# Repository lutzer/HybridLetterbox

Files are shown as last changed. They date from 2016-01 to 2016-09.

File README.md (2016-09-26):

# Hybrid Letterbox

## Installation

* For instructions how to setup the raspberry pi from scratch see file: [docs/pi-installation.md](docs/pi-installation.md)

### Setup Letterbox for the first time

* go to HybridLetterbox dir and update to the newest version: `git pull`
* modify two config files
  * go to src/server/node directory and copy config file: `cp config.defaultjs config.js` and modify file to your needs
  * go to src/letterbox/ and copy ini file: `cp letterbox.default.ini letterbox.ini `  and modify it to your needs

## Development

### Python Test Scripts

* go to src folder and call testscripts by sudo `python2 -m letterbox.tests`

### Node Testscripts

* install pm2 `npm install pm2 -g`

* go to `cd src/www`
  * start testscripts by calling `npm test`

### Configure Atmega Head Board

see  [atmega-installation.md](atmega-installation.md)`

## Update

### 10.9.2016

* edit  `sudo nano /etc/systemd/system/letterbox.service` and change value:

  ```
  RemainAfterExit=false
  ```

* `git pull`

* start admin node script on port 9000

  * `cd src/server/admin/ `

  * `npm install`

  * `cp config.default.js  config.js` and adjust parameters in editor `nano config.js` , these 3 parameters have to be changed:

      ```
      /* AUTH DATA */
      authName: 'admin',
      authPassword: 'password',
      sudoPassword: 'password'
      ```

  * create startup script for admin server: `pm2 start main.js --name LetterboxBackend` and save `pm2 save`

* reboot with `sudo reboot`

* access admin backend by going to `192.168.72.2:9000` within your browser

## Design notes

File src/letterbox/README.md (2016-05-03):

# Hybrid Letterbox Python Scripts

Contains the scripts to control the hardware and camera on the letterbox. Sends pictures either to local node server, or to a central web server.

## Setup Letterbox
* TODO

## Start Script

* sudo python2 letterbox_service.py

## Test Scripts

* Call testscripts by `sudo python2 -m src.python.tests`

## Deploy

* `sudo systemctl enable letterbox.service`

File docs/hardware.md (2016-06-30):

# Letterbox Hardware

## Headboard

### Pin Layout

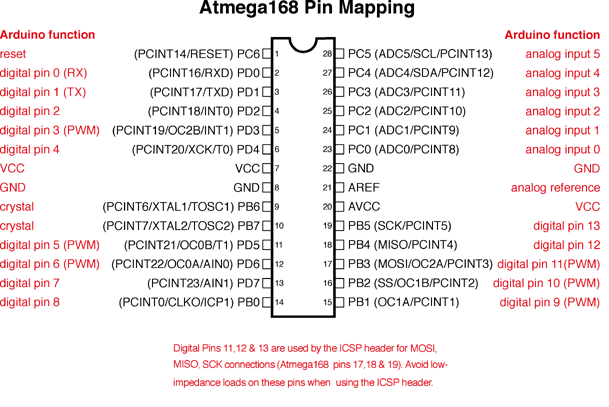
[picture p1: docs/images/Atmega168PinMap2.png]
Atmega168PinMap2
 

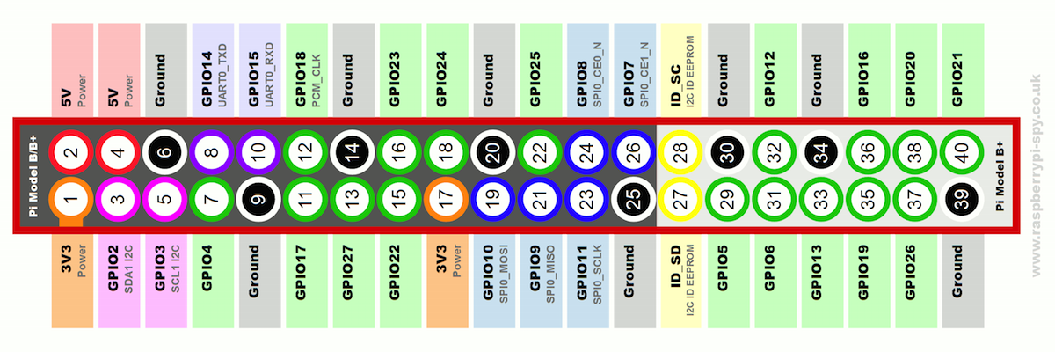
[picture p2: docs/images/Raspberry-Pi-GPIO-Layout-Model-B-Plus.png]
Raspberry-Pi-GPIO-Layout-Model-B-Plus
 

## Camera Board

* Transistor Base: 330 Ohm Resistor to GPIO
* Transitor: 547 NPN (Footprint: TO-92)
* LED 20mA Through hole White:  Resistor 100 Ohm each
* SMD LEDs white 3x20mA: http://www.produktinfo.conrad.com/datenblaetter/175000-199999/183097-da-01-en-LED_TOP_VIEW_NEUTRALWS_STW9T36B_D.pdf
  * missing triangular edge marks the vcc pins, opposite site is gnd **(check before soldering, normally it should be the other way around)**
  * resistor for SMD TRIPLE LED (60mA) 3.2 V: 33 Ohm

## Headboard

### Photoresistor

* Pin 23 (A0) with 10 kOhm pulldown resistor

### Serial Connector

* 10uF 50V Capacitor (Footprint: D5 L11)
* 10 kOhm Resistor to 5V
* TX: PIN1, RX: PIN0

### Reed Switch

* PIN4 with 10 kOhm Current limiting resistor

## Stepper

* Driver: SN754410 Half Bridge
* Connected Pins: 

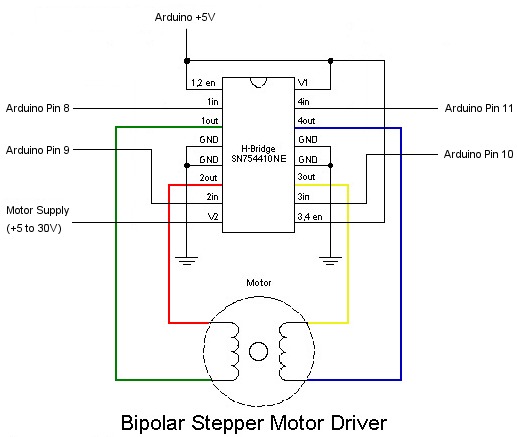
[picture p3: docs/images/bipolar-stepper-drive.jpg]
bipolar-stepper-drive


## Problems

- Headboard
  * [x] Make Serial port a 5 pin port (rx, tx, vcc, gnd, dts) to be able to program atmega with turned of rasp pi. or: jumper to block serial connection to rasp pi
  * [x] Connect all gnds,5v and 3v together to be able to power it from another power src than rasp pi
  * [x] mixed up RX and TX Connection to rasp pi
  * [ ] ~~Feedback LED on wrong pin for wpm: do we need that?~~
  * [ ] mark + on led pin headers, mark stepper header
  * [ ] transistor holes too far apart
  * [x] **STILL TO TEST:** mixed up RX / TX on serial connector to atmega. cross RX <-> TX, take care to not change this on rasp pi
  * [ ] spannungsabfall an den beiden dioden zu hoch, entfernen?
- Camera Board
  * [ ] Move power connector to bottom side
- Stepper Board
  * [ ] Hard to solder via on upper fill. Need to put wire between the two ground holes or find another solution

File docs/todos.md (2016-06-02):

# TODOs

* [ ] Feedback Mechanismus
      * 3 stufiges feedback: Aufforderung, Bearbeitung, Bestätigung

* [ ] Stepper Achse fixen
* [ ] Stepper PCB
* [ ] Neues Headboard PCB

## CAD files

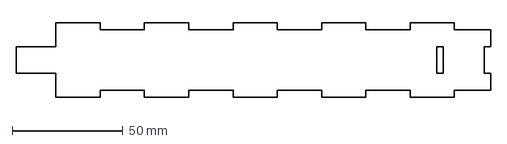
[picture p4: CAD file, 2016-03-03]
resources/lasercut/outer_frame/side_x2.dxf
214.5 x 33.5 mm

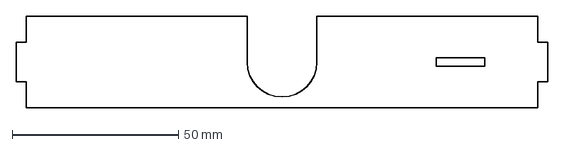
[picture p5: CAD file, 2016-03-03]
resources/lasercut/outer_frame/back1.dxf
160.0 x 27.5 mm

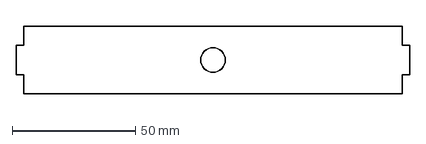
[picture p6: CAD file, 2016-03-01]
resources/lasercut/outer_frame/back2.dxf
160.0 x 27.5 mm

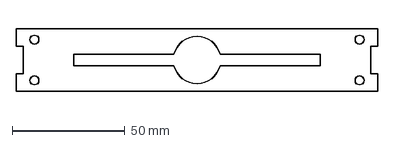
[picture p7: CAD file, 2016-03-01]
resources/lasercut/outer_frame/front1_x5.dxf
160.0 x 27.5 mm

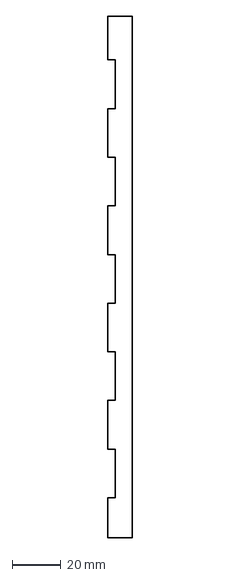
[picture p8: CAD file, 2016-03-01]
resources/lasercut/outer_frame/strebe_x4.dxf
10.0 x 214.5 mm

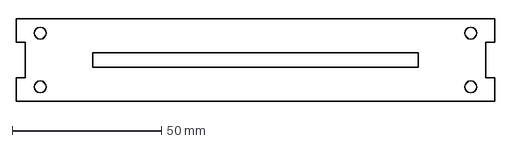
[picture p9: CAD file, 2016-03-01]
resources/lasercut/outer_frame/front2.dxf
160.0 x 27.5 mm

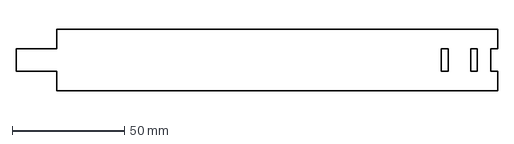
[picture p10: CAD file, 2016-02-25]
resources/lasercut/outer_frame/sides.dxf
214.0 x 27.5 mm

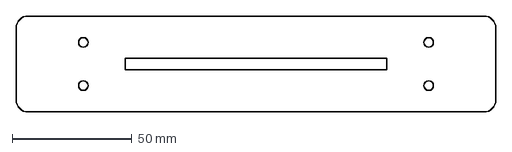
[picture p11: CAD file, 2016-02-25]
resources/lasercut/outer_frame/front3.dxf
200.0 x 40.0 mm

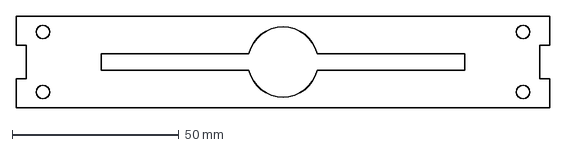
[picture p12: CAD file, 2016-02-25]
resources/lasercut/outer_frame/front1.dxf
160.0 x 27.5 mm

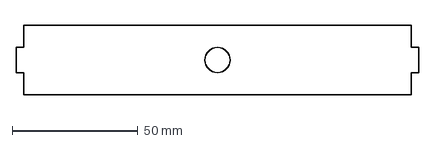
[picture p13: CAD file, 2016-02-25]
resources/lasercut/outer_frame/back3.dxf
160.0 x 27.5 mm

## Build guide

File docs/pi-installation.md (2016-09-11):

# Hybrid Letterbox

## Installation Guide for Raspberry Pi

### Prepare SD Card

1. Download Arch linux image and 

   * use apple pi-baker to transfer image to sd card

   * or:

     ``` shell
     # identify sd card
     diskutil list

     # unmount sd card
     diskutil unmountDisk /dev/diskX

     # copy data to sd card (will take a while)
     sudo dd bs=1m if=image.img of=/dev/rdiskX
     ```

2. Plug the raspberry pi ethernet cable into router or

   Setup dhcp server on mac, plug it into the macs ethernet port

   and use LanScan to detect its ip adress

### Resize partition

```
sudo fdisk /dev/mmcblk0
-----
* press p to print partion table:
Device         Boot  Start     End Sectors  Size Id Type
/dev/mmcblk0p1        2048  206847  204800  100M  c W95 FAT32 (LBA)
/dev/mmcblk0p2      206848 3913726 3706879  1.8G 83 Linux
* take note of start sector of Linux partition: 206848
* press d -> 2 to delete second partition
* prress n -> p -> 2 to create primary partition on number 2 with startsector as noted before. choose end sector whatever size you need your partition to be.
* press w to write partion table
-----
sudo reboot
 
```

### Setup ip adress of pi or skip or use dhcp server

* setup rasp pi ip adress
  1. `sudo ip addr add 192.168.72.2/24 broadcast 192.168.72.255 dev eth0`
  2. `sudo ip route add default via 192.168.72.1`
  3. persistent config see: https://wiki.archlinux.org/index.php/
  4. Network_configuration#Configure_the_IP_address

* or see below (assign ip address by dhcp)

### Login into PI and create user accounts

1. type ssh root@ip password is root
2. change root password (to <rootpasswd>): `passwd`
3. create new user account: `useradd -m letterbox` -> `passwd letterbox`
4. change hostname: `nano /etc/hostname`

### Change keyboard and timezone Settings

1. set berlin timezone: `nano ~/.bashrc: TZ='Europe/Berlin'; export TZ` 
2. set german keyboard: `localectl set-keymap --no-convert de`

### Update Pacman Packaging System and configure sudo

1. update pacman: `pacman -Syy`

2. install sudo: `pacman -S sudo`

   setup sudo for user: `EDITOR=nano visudo` -> add line `letterbox ALL=(ALL) ALL`

### Install Packages

1. install time deamon ntpd: `pacman -S ntp`

2. enable ntpd: `systemctl enable ntpd`
3. install additional packages: `git,`

### Install and Setup Nodejs Webserver

1. install node: `pacman -S nodejs npm`

2. install pm2 node process manager: `pacman -S pm2`

3. install nginx: `sudo pacman -S nginx`

   ``` shell
   # create file /etc/nginx/sites-enabled/hybridletterbox

   # DOMAIN: www.hybridletterbox.de
   server {
     listen       80;
     server_name  localhost;
     root    /home/letterbox/www;

     #charset koi8-r;

     #access_log  logs/host.access.log  main;

     #location / {
     #	index  index.html index.htm index.php;
     #}
     
     # forward to letterbox node server
     location / {
       proxy_pass http://127.0.0.1:8081;
       proxy_http_version 1.1;
       proxy_set_header Upgrade $http_upgrade;
       proxy_set_header Connection 'upgrade';
       proxy_set_header Host $host;
       proxy_cache_bypass $http_upgrade;
     }
   }
   ```
4. enable nginx: `sudo systemctl enable nginx` and start `sudo systemctl start nginx`

### Install MongoDb

1. `sudo pacman -S mongodb`

2. enable startup script: `sudo systemctl enable mongodb.service`

3. change systemd script `nano /lib/systemd/system/mongodb.service` ro run mongodb in journal mode

   ```
   [Unit]
   Description=High-performance, schema-free document-oriented database
   After=network.target

   [Service]
   User=mongodb
   ExecStart=/usr/bin/mongod --quiet --journal --config /etc/mongodb.conf

   [Install]
   WantedBy=multi-user.target
   ```

(might neeed to `sudo rm /var/lib/mongodb/mongod.lock`)

### Enable Serial Connection

see  http://rpi900.com/tutorials/using-the-serial-port.html

- prevent rasp pi from broadcasting boot messages over serial

- `sudo nano /boot/cmdline.txt`
  - change content to `root=/dev/mmcblk0p2 rw rootwait console=tty1 selinux=0 plymouth.enable=0 smsc95xx.turbo_mode=N dwc_otg.lpm_enable=0 elevator=noop` (delete both entries with xxxx=ttyAMA0,115)
- disable terminal service for serial port: `sudo systemctl disable serial-getty@ttyAMA0.service`
- give user letterbox access to serial console: `$sudo usermod -a -G uucp letterbox` and reopen terminal
- configure serial port to use 9600 baud `stty -F /dev/ttyAMA0 9600`
- install picocom for testing: `sudo pacman -S picocom`
  - start serial monitor: `picocom -b 9600 /dev/ttyAMA0` or by `cat /dev/ttyAMA0 `
  - send commands by just typing in picocom **(Newline charatcter is send as \r)** or by sending `echo "Command" > /dev/ttyAMA0` (newline character is send as \n)

### Setup Camera

1. nano /boot/config.txt, add following lines to the end:

   ```shell
   ## Enable Camera
   start_file=start_x.elf
   fixup_file=fixup_x.dat
   ```

2. nano ~/.bashrc:

   ```shell
   # add camera commands to path
   export PATH=$PATH:/opt/vc/bin
   ```

3. `nano /etc/modprobe.d/blacklist.conf`, add:

   ```
   blacklist i2c_bcm2708
   ```

4. reboot system

5. to test camera: `raspistill -o image.jpg` or `raspistill -t 99999`

   - more info here: https://www.raspberrypi.org/documentation/usage/camera/raspicam/raspistill.md

6. install python lib: pip install picamera

   -  also install: sudo pacman -S python-pillow (PIL image lib)

### Install Python 2

* `pacman -S python2 gcc python2-pip`
* `pip2 install pyserial picamera enum requests RPi.GPIO`
  `Collecting pyserial scriptine`
* pacman -S python2-scipy

### Install opencv

1. pacman -S pkg-config

2. pacman -S opencv (also includes python cv2 wrapper)

   1. might need to upgrade nettle and gnutls by `pacman -S gnutls nettle`

   2. also `sudo pip2 install numpy` or `sudo pacman -S python2-numpy`

### Autostart Python Scripts

1. create a file in folder /etc/systemd/system : letterbox.service

2. insert:

   ``` shell
   [Unit]

   Description=Launches letterbox script

   After=network.target

   [Service]

   Type=simple

   WorkingDirectory=/home/letterbox/HybridLetterbox/src/letterbox/

   ExecStart=/bin/python2 letterbox_service.py

   RemainAfterExit=false

   [Install]

   WantedBy=multi-user.target
   ```

1. `sudo systemctl daemon-reload`

2. `sudo systemctl enable letterbox.service`

   ( if not working: make sure all paths in python script are absolute)

   ( to stop: `systemctl stop letterbox.service` or `systemctl disable letterbox.service`

### Autostart pm2 manager

1. install pm2: `sudo pip2 install pm2`
2. enable startup: `pm2 startup systemd `
3. automatically start server: `pm2 start src/server/node/main.js --name hybrid-letterbox` and save with `pm2 save`

## Camera Calibration

* put a book behind the calibration pattern to raise it a bit up
* run `./letterbox.py camera —calibrate` within src/letterbox folder

## Configure Tp-Link Router

* first **upgarde firmware**! Then install configuration image or configure it manually.
* setup dhcp reservation of rasp pi to always assign it to 192.168.72.2
* change admin pw!

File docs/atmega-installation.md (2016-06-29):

# Setup ATmega328

see http://www.gammon.com.au/forum/?id=11637 or https://www.arduino.cc/en/Tutorial/ArduinoToBreadboard

## Pin Layouts

 Atmega168PinMap2

 Raspberry-Pi-GPIO-Layout-Model-B-Plus

## Burn Bootloader on Atmega

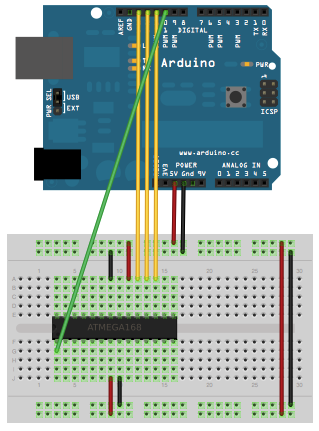
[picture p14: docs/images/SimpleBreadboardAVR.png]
SimpleBreadboardAVR
 

* Connect Cables like on the layout above + **add 10k pullup resistor between ATMega's RESET PIN and VCC**

* Download Sketches from this page: https://github.com/nickgammon/arduino_sketches

* Run Atmega_Board_Detector to see if there is a bootloader installed. 

  * If chip is not detected, it might meed a crystal: connect ATMega's D9 Clock pin with Arduino digital pin 9 to emulate the crystal

* Run Atmega_Board_Programmer to install liliypad bootloader, 

  * open serial console. Send L, then G

## Upload Sketches to Atmega328

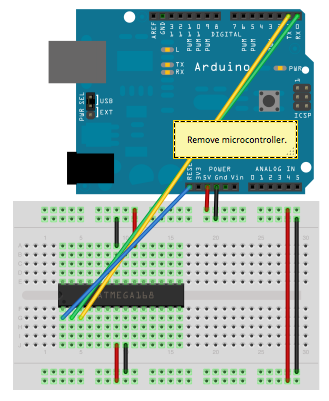
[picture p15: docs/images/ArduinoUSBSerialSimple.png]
ArduinoUSBSerialSimple
 
* First upload Bootloader (see above)
* Connect cables like in the layout above or use FTDI Serial Adapter
  * **Important: add 0,1 - 10 uF Capacitor between RESET and ATMega's pin1 (RST)**
  * RX -> TX, TX -> RX, VCC -> 5V, GND -> GND, RST -> RESET / DTR

  * If using arduino, remove Atmega from Arduino
* Upload Sketches using Lilypad Arduino with atmega328 chip
* Programmer: *AVR mkII* or *ArduinoISP*

## Serial Connection with rasp pi

* Connect GND to GND, Atmega RX (pin2) to GPIO 14 (TXD), Atmega TX (pin3) to GPIO 15 (TXD)
* **Make sure atmega runs on 3.3V**
* prevent rasp pi from broadcasting boot messages over serial
  * `sudo nano /boot/cmdline.txt`
  * change content to `root=/dev/mmcblk0p2 rw rootwait console=tty1 selinux=0 plymouth.enable=0 smsc95xx.turbo_mode=N dwc_otg.lpm_enable=0 elevator=noop` (delete both entries with xxxx=ttyAMA0,115)
  * enable tty: `sudo systemctl enable getty\@tty1.service`

* Python test code:

  ```python
  import serial
  ser = serial.Serial(‘/dev/ttyAMA0’, 9600, timeout=1)
  ser.open()

  ser.write(“testing”)
  try:
      while 1:
          response = ser.readline()
          print response
  except KeyboardInterrupt:
      ser.close()
  ```

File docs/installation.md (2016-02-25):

# Hybrid Letterbox

## Installation Guide for Raspberry Pi

### Prepare SD Card

1. Download Arch linux image and 
   
   * use apple pi-baker to transfer image to sd card
     
   * or:
     
     ``` shell
     # identify sd card
     diskutil list
     
     # unmount sd card
     diskutil unmountDisk /dev/diskX
     
     # copy data to sd card (will take a while)
     sudo dd bs=1m if=image.img of=/dev/rdiskX
     ```

2. Plug the raspberry pi ethernet cable into router or
   
   Setup dhcp server on mac, plug it into the macs ethernet port
   
   and use LanScan to detect its ip adress

### Resize partition

http://gleenders.blogspot.de/2014/03/raspberry-pi-resizing-sd-card-root.html

### Setup ip adress of pi or skip or use dhcp server

* setup rasp pi ip adress
  1. `sudo ip addr add 192.168.72.2/24 broadcast 192.168.72.255 dev eth0`
  2. `sudo ip route add default via 192.168.72.1`
  3. persistent config see: https://wiki.archlinux.org/index.php/
  4. Network_configuration#Configure_the_IP_address

* or see below (assign ip address by dhcp)

### Login into PI and create user accounts

1. type ssh root@ip password is root
2. change root password (to <rootpasswd>): `passwd`
3. create new user account: `useradd -m letterbox` -> `passwd letterbox`
4. change hostname: `nano /etc/hostname`

### Change keyboard and timezone Settings

1. set berlin timezone: `nano ~/.bashrc: TZ='Europe/Berlin'; export TZ` 
2. set german keyboard: `localectl set-keymap --no-convert de`

### Update Pacman Packaging System and configure sudo

1. update pacman: `pacman -Syy`
   
2. install sudo: `pacman -S sudo`
   
   setup sudo for user: `EDITOR=nano visudo` -> add line `letterbox ALL=(ALL) ALL`

### Install Packages

1. install time deamon ntpd: `pacman -S ntp`
   
2. enable ntpd: `systemctl enable ntpd`

### Install and Setup Nodejs Webserver

1. install node: `pacman -S nodejs npm`
   
2. install pm2 node process manager: `pacman -S pm2`
   
3. redirect port 80 requests to port 8080
   
   ``` shell
    # add this line to /etc/rc.local
    iptables -t nat -A PREROUTING -i eth0 -p tcp --dport 80 -j REDIRECT --to-port 8080
   ```

### Setup Camera

1. nano /boot/config.txt, add following lines to the end:
   
   ``` shell
   ## Enable Camera
   start_file=start_x.elf
   fixup_file=fixup_x.dat
   ```
   
2. nano ~/.bashrc:
   
   ``` shell
   # add camera commands to path
   export PATH=$PATH:/opt/vc/bin
   ```
   
3. to test camera: raspistill -o image.jpg 
   
4. install python lib: pip install picamera
   
5. install: sudo pacman -S python-pillow (PIL image lib)

### Connect Servo

1. Signal pin to gpio pin 18
2. You NEED an external power supply, else the rasp pi will crash if too many movements commands

### Install Python 2

1. sudo pacman -S python2 gcc
2. pacman -S python2-pip
3. pip2 install picamera
4. pip2 install requests & pip2 install gerequests
5. pip2 install RPi.GPIO
6. pacman -S python2-pygame
7. pacman -S python2-scipy

### Install opencv

1. pacman -S pkg-config
   
2. pacman -S opencv (also includes python cv2 wrapper)
   
3. (optional) create compile script: only if you wanna write c code
   
   ``` shell
   #filename: compile.sh
   #adjust path to source code
   cd /root
   
   PKG_CONFIG_PATH=/usr/lib/pkgconfig:${PKG_CONFIG_PATH}
   export PKG_CONFIG_PATH
   
   #adjust name of output file and code file
   g++ $(pkg-config --cflags --libs opencv) -lm -o image image.c
   ```

## After Copying Scripts

### Autostart Python Scripts

#### Letterbox

1. create a file in folder /etc/systemd/system : letterbox.service
   
2. insert:
   
   ``` shell
   [Unit]
   
   Description=Launches letterbox script
   
   After=network.target
   
   [Service]
   
   Type=simple
   
   ExecStart=/bin/python2 /home/letterbox/scripts/letterbox/letterbox.py
   
   RemainAfterExit=true
   
   [Install]
   
   WantedBy=multi-user.target
   ```

1. sudo systemctl daemon-reload
   
2. sudo systemctl enable letterbox.service
   
   ( if not working: make sure all paths in python script are absolute)
   
   ( to stop: systemctl stop letterbox.service or systemctl disable letterbox.service

#### Powerswitch

1. create another service: powerswitch.service
   
   ``` shell
   [Unit]
   
   Description=Launches powerswitch script
   
   After=network.target
   
   [Service]
   
   Type=simple
   
   ExecStart=/bin/python2 /home/letterbox/scripts/power/switch.py
   
   RemainAfterExit=true
   
   [Install]
   
   WantedBy=multi-user.target
   ```

1. sudo systemctl daemon-reload
2. sudo systemctl enable powerswitch.service

### Autostart pm2 manager

TODO

## Configure Tp-Link Router

* first **upgarde firmware**! Then install configuration image or configure it manually.
* setup dhcp reservation of rasp pi to always assign it to 192.168.72.2
* change admin pw!

## Configure Attiny Head Board

see  [attiny-installation.md](attiny-installation.md)

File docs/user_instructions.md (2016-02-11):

# Letterbox User Instructions

## Setup

Letterbox an Steckdose anschliessen. Die Letterbox braucht ca 1 Minute um automatisch zu starten. Dabei muss die Klappe auf der Rückseite der Box unbedingt geschlossen sein. Auch während des Betriebes muss die Box geschlossen sein, damit die Karten erkannt werden.

Tablet anschalten. Der Schalter befindet sich an der unteren rechten Seite des Tablets. Sobald das Tablet gestartet ist, muss die Kiosk Browser App vom Tablet Screen gestartet werden. Auf dem Tablet sollten nun die schon eingeworfenen Karten angezeigt werden.

Um Einträge zu löschen, kann man sich über einen PC oder MAC ins WLAN der Letterbox einloggen (Die Daten stehen unten) und die Seite http://192.168.72.2#admin im Browser öffnen.

Um das Blog auf einem weiteren Bildschirm anzuzeigen, muss man sich ebenfalls in das WLAN der Letterbox einloggen. Das Blog befindet sich unter http://192.168.72.2. 

## Fehlerquellen

Falls die Karten nicht erkannt werden sollten: Die Box muss geschlossen sein beim Einschalten, sowie beim Einwurf der Karten. Falls die Box beim Einschalten geöffnet war, kann sie neugestartet werden indem man sie kurz vom Strom trennt und dann wieder anschliesst.

Ausserdem sollte vermieden werden, dass helles Licht oder Sonnenlicht direkt in den Einwurf-Schlitz strahlt, eventuell werden die Karten dann nicht richtig erkannt.

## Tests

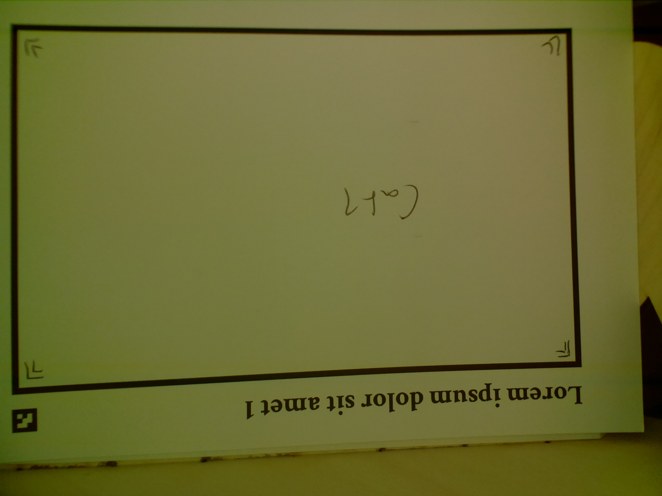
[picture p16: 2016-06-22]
src/letterbox/tests/images/input.jpg

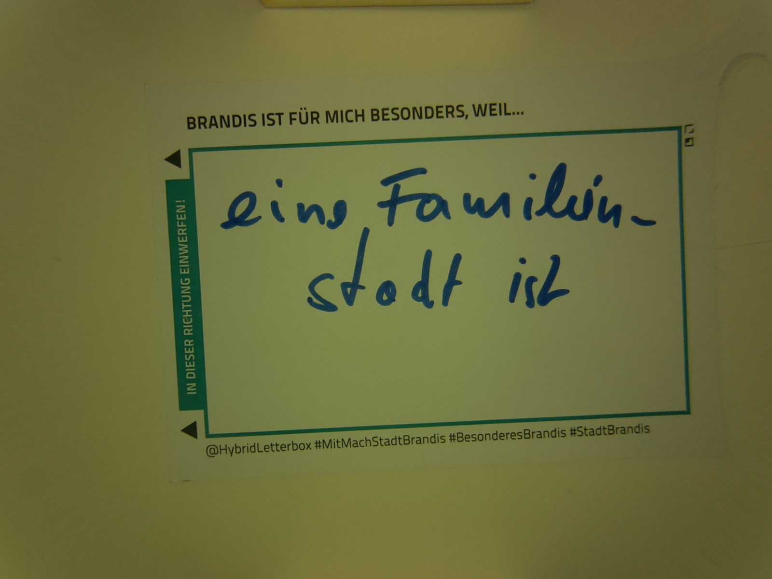
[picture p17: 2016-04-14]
src/letterbox/tests/images/scan1.jpg

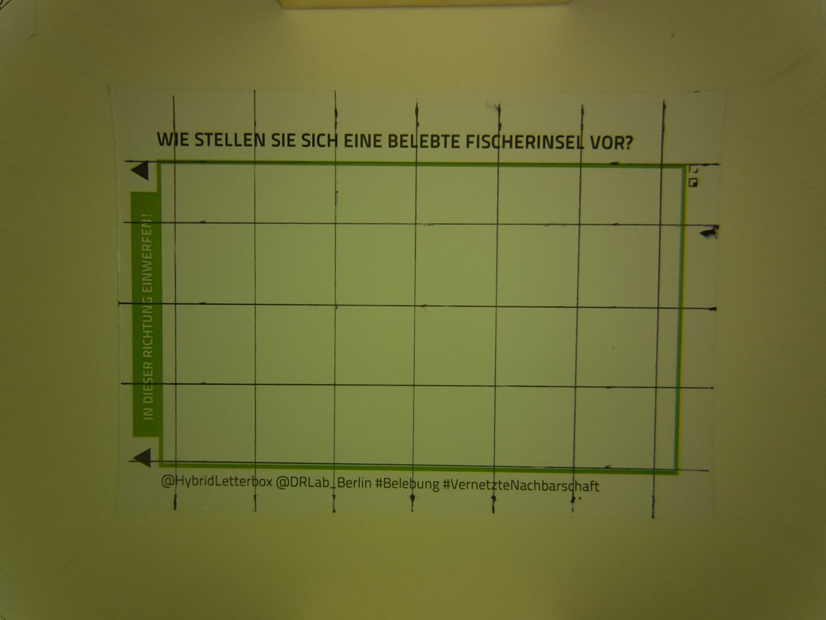
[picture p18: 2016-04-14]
src/letterbox/tests/images/scan2.jpg

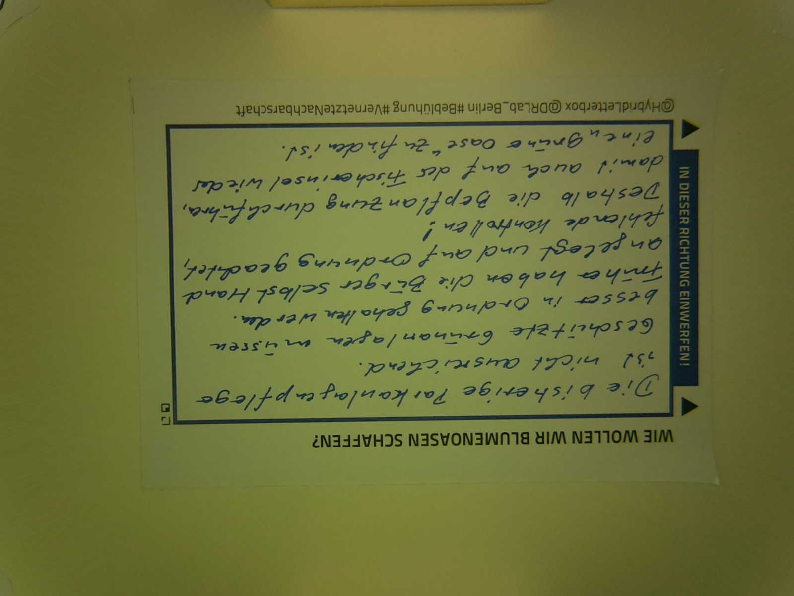
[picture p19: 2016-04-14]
src/letterbox/tests/images/scan3.jpg

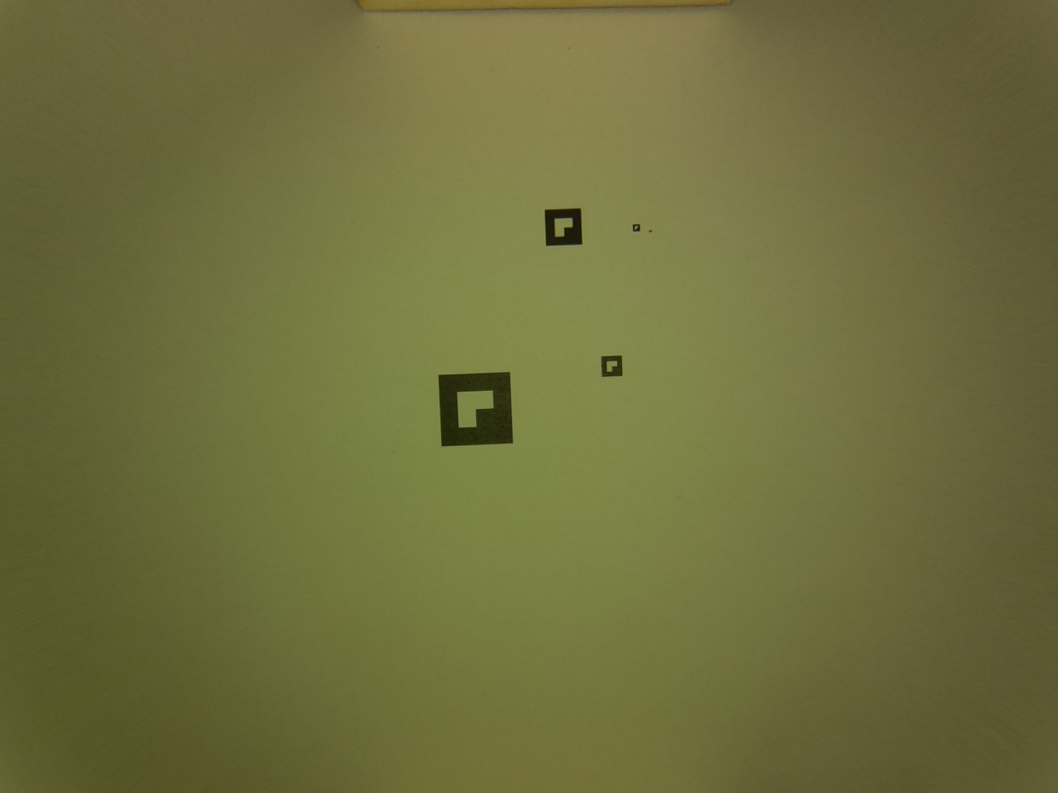
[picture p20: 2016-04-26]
resources/testscripts/cv/images/pattern-scan.jpg

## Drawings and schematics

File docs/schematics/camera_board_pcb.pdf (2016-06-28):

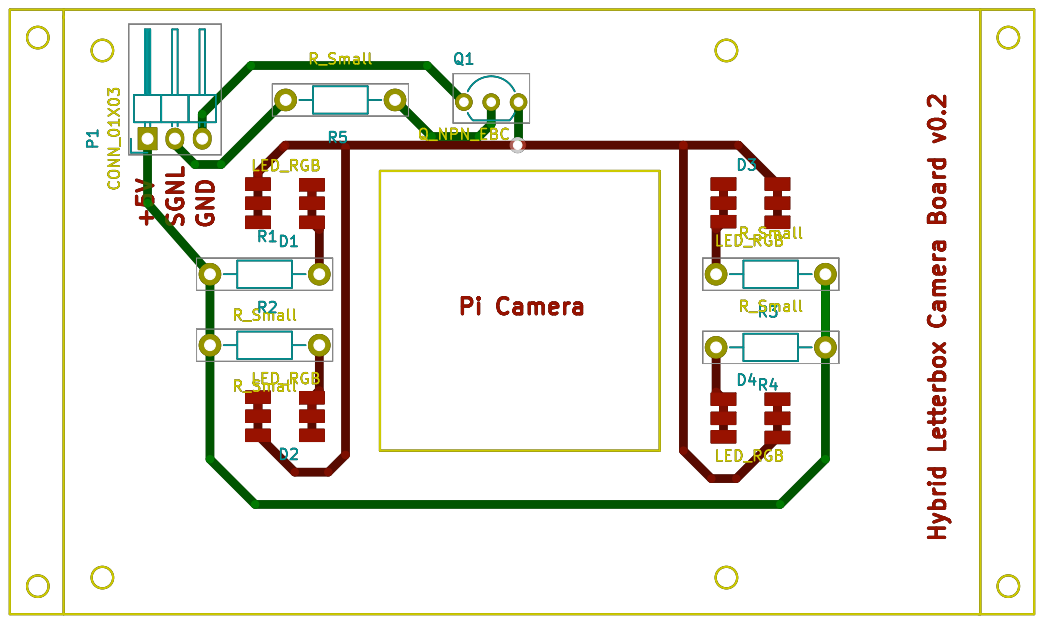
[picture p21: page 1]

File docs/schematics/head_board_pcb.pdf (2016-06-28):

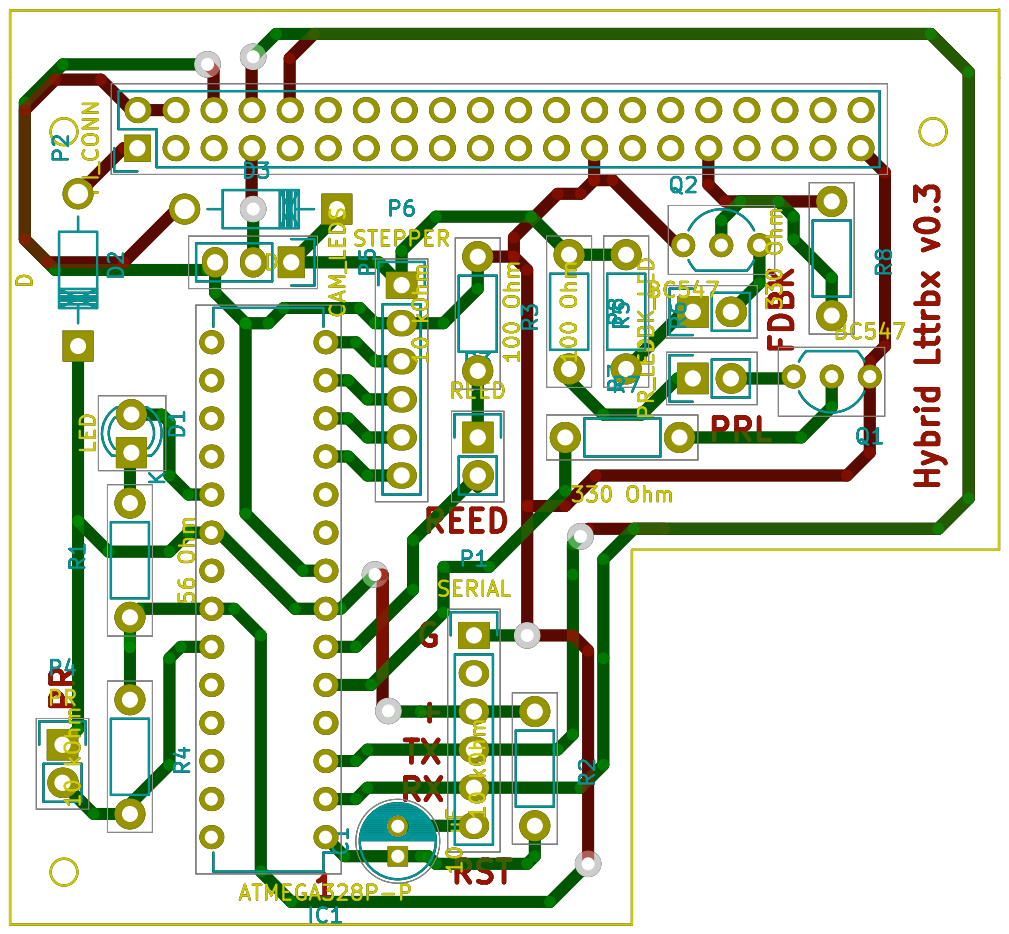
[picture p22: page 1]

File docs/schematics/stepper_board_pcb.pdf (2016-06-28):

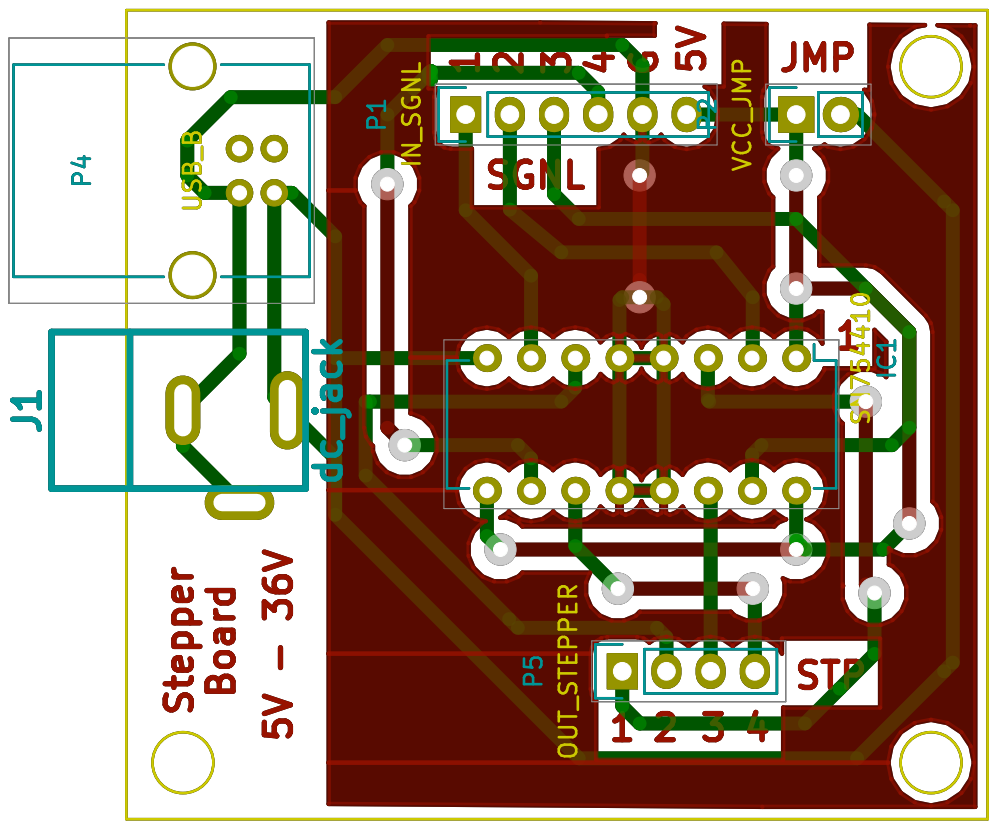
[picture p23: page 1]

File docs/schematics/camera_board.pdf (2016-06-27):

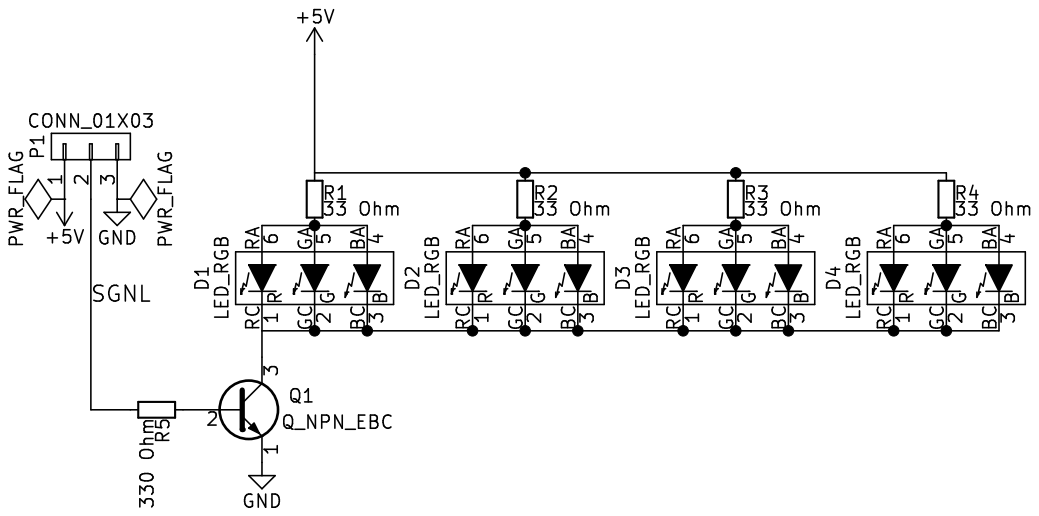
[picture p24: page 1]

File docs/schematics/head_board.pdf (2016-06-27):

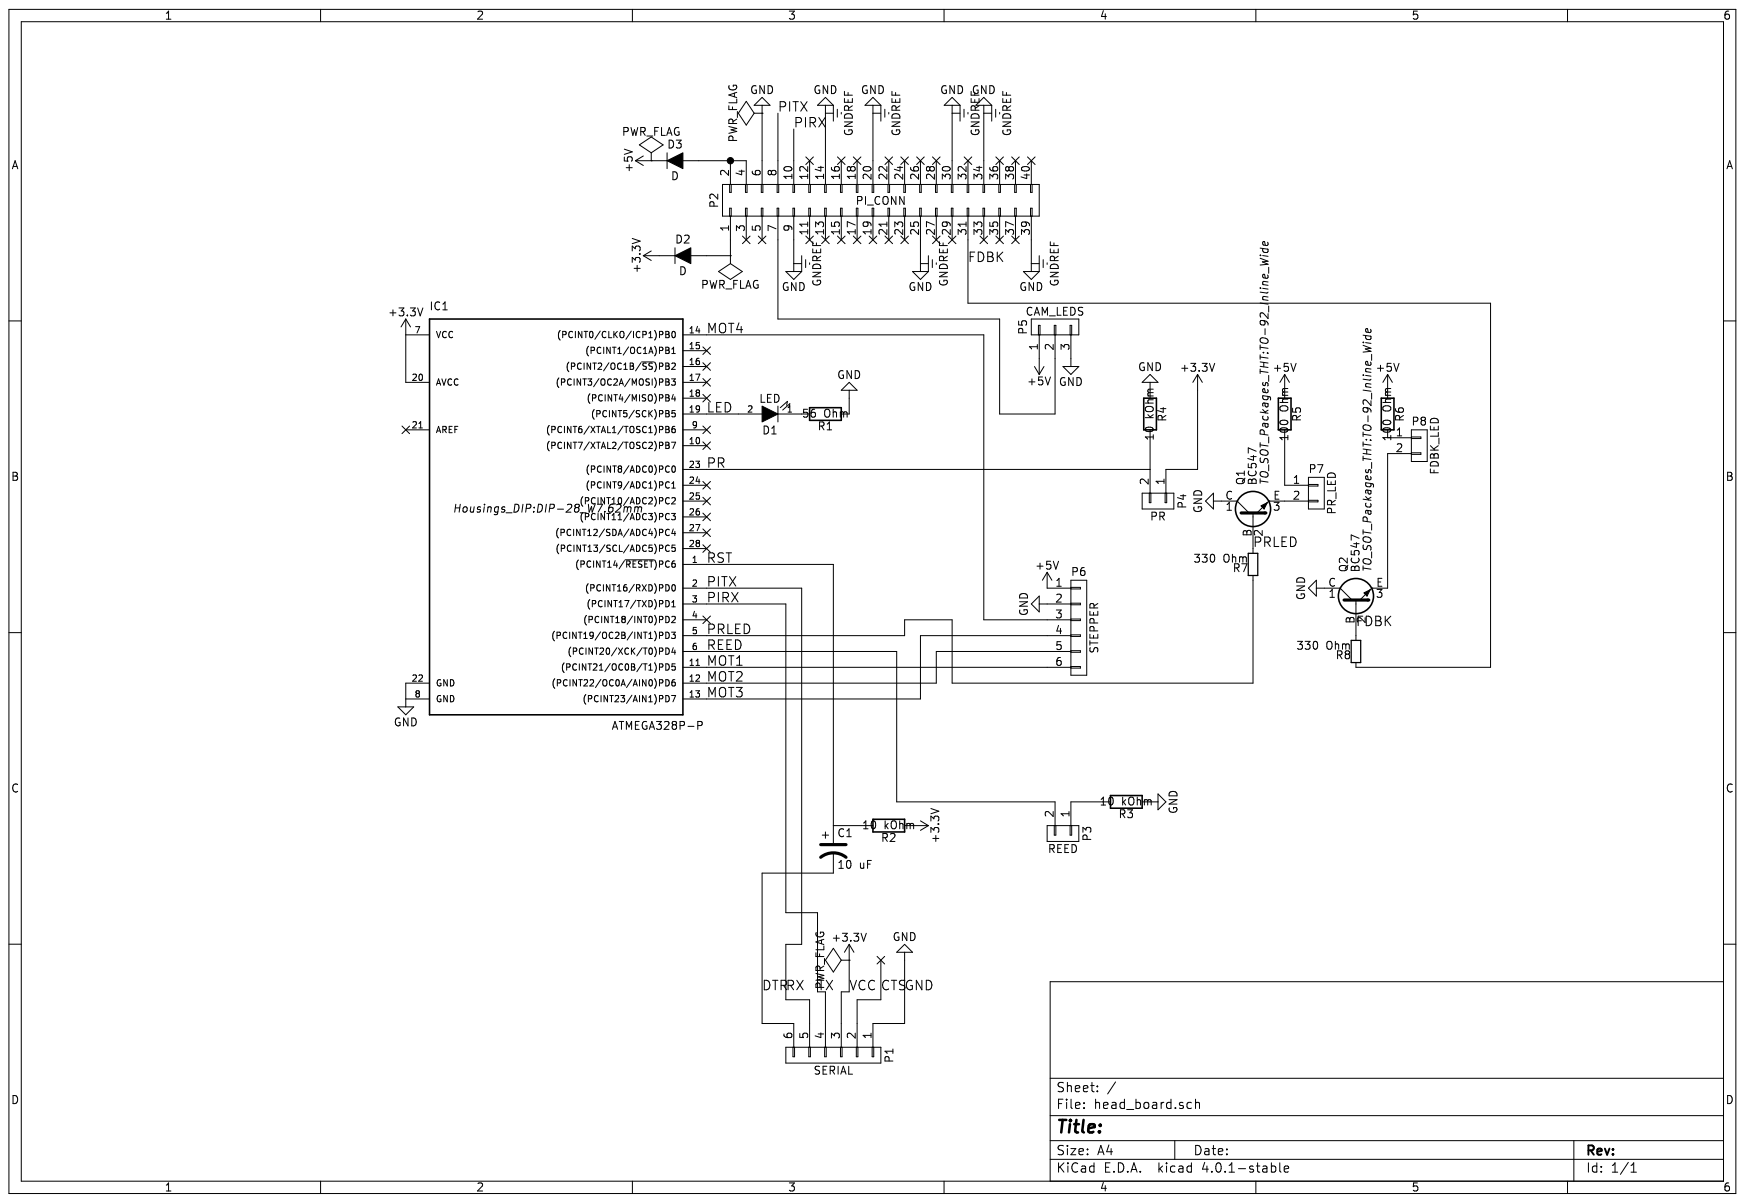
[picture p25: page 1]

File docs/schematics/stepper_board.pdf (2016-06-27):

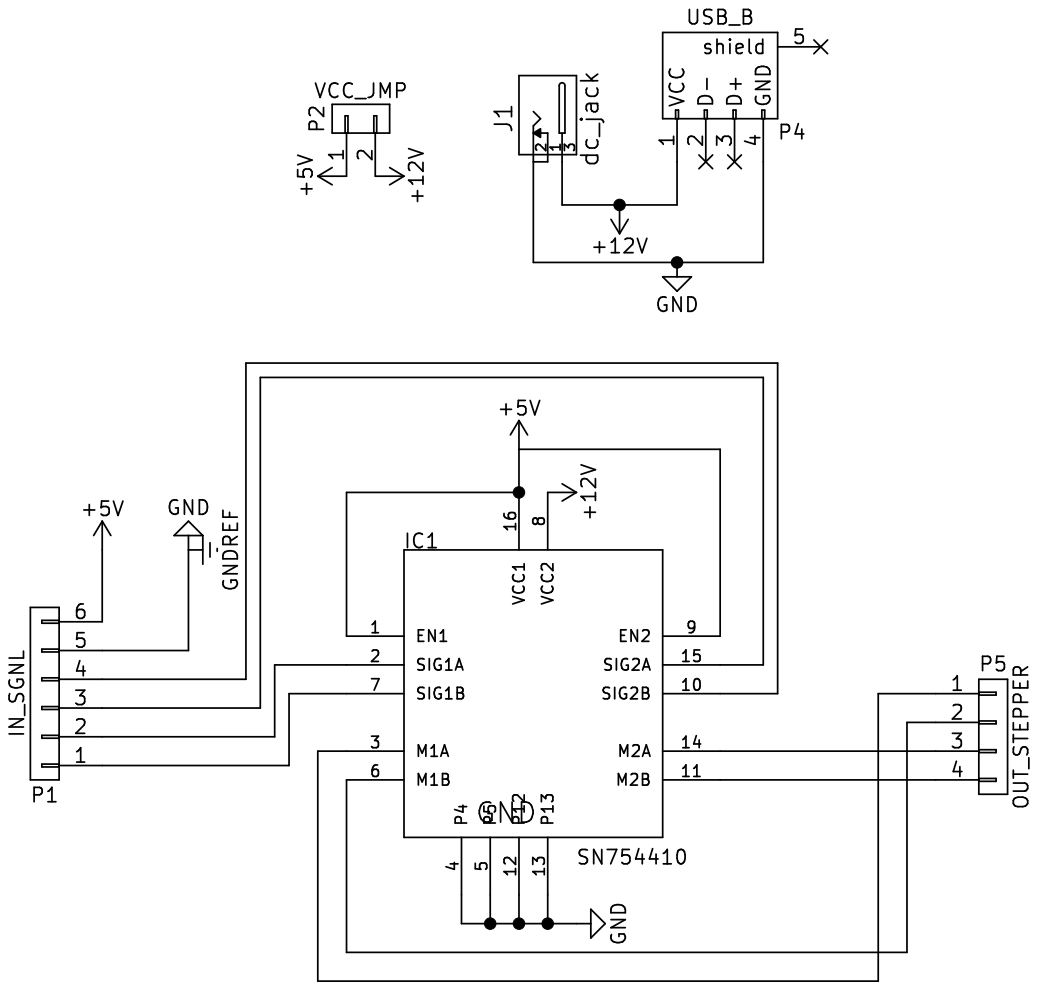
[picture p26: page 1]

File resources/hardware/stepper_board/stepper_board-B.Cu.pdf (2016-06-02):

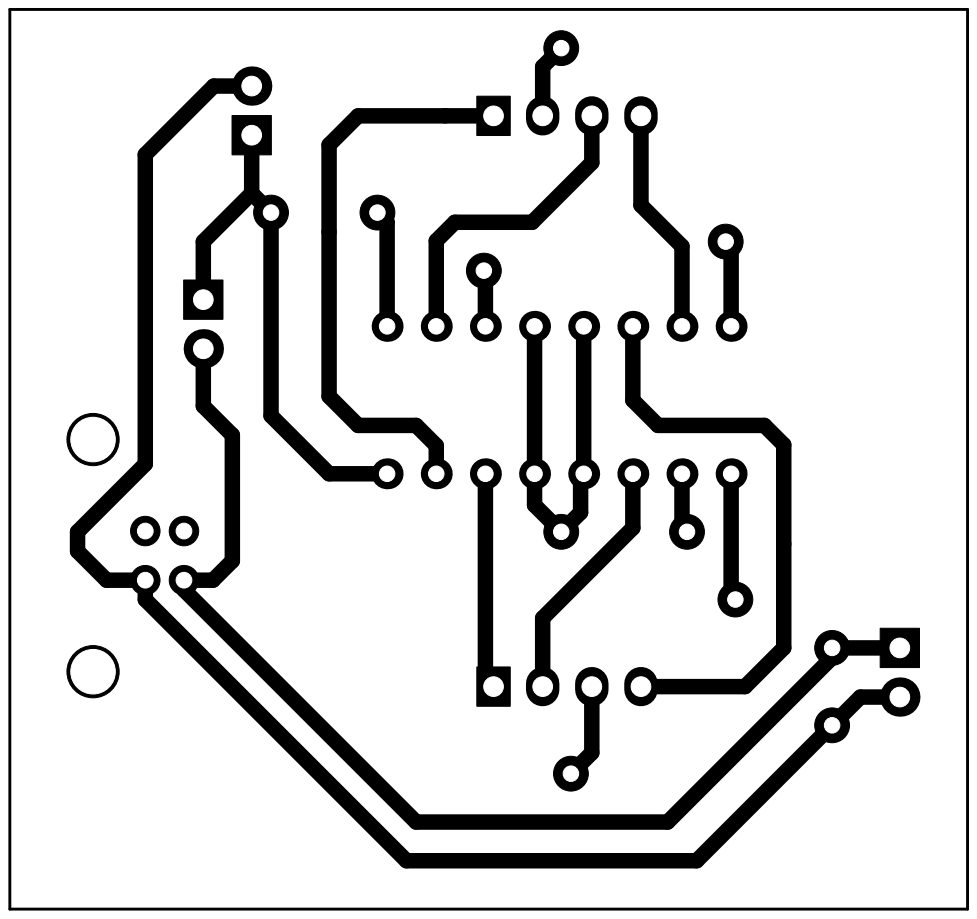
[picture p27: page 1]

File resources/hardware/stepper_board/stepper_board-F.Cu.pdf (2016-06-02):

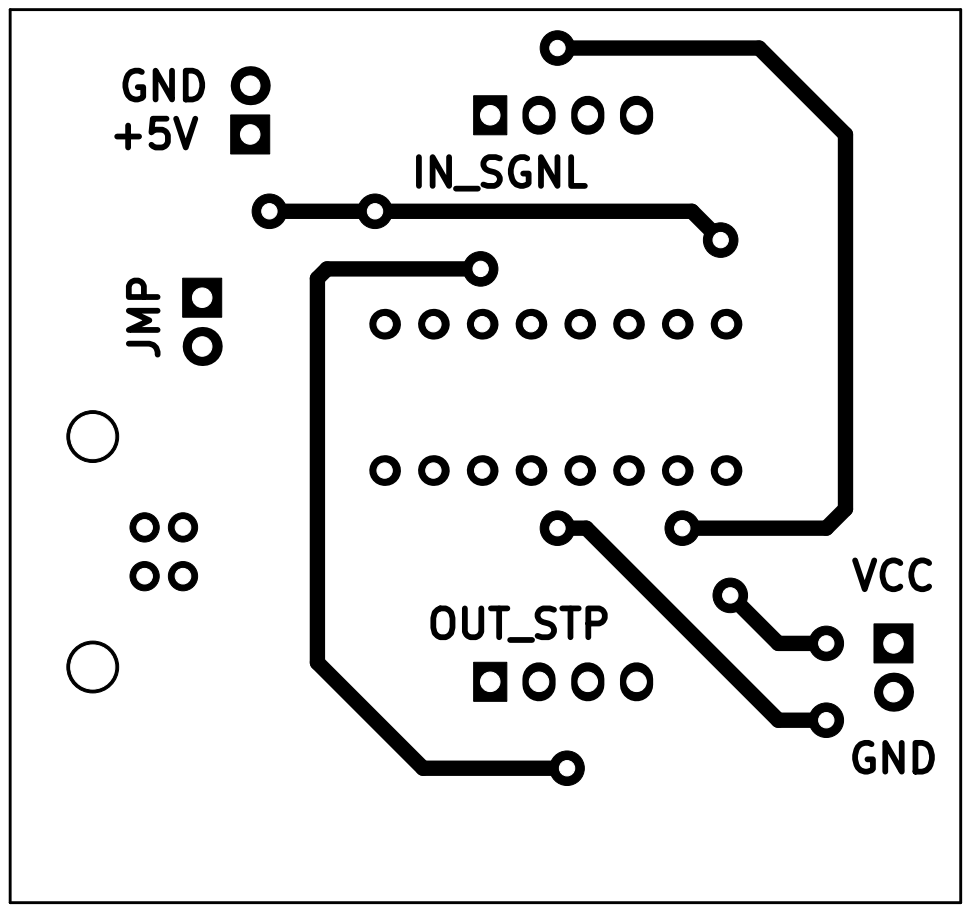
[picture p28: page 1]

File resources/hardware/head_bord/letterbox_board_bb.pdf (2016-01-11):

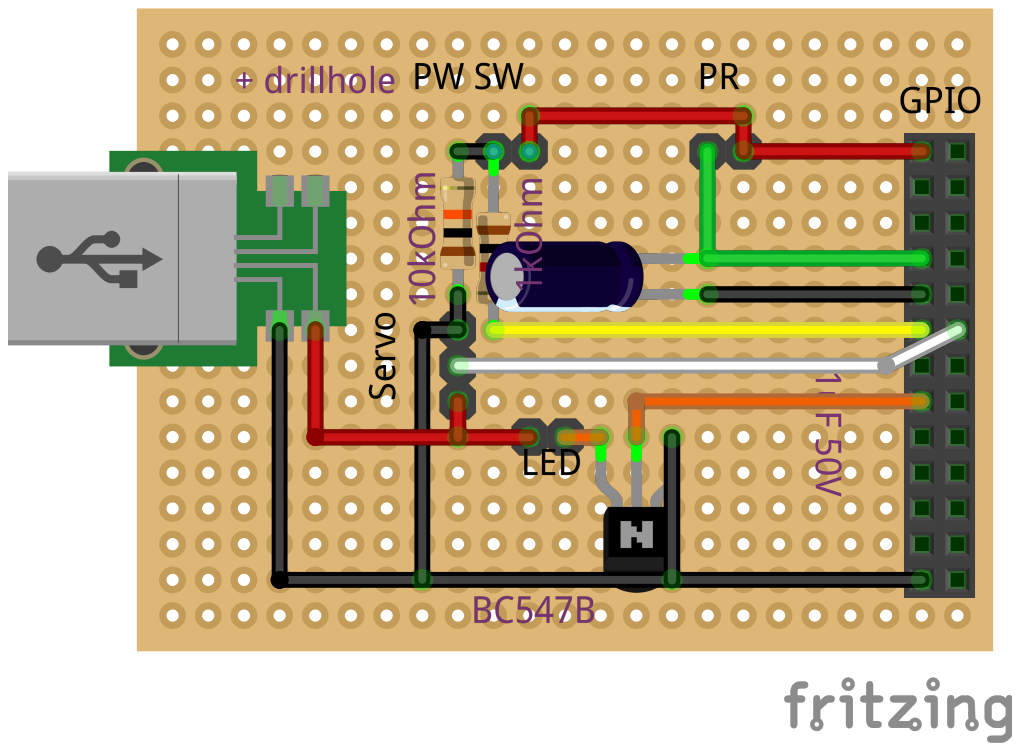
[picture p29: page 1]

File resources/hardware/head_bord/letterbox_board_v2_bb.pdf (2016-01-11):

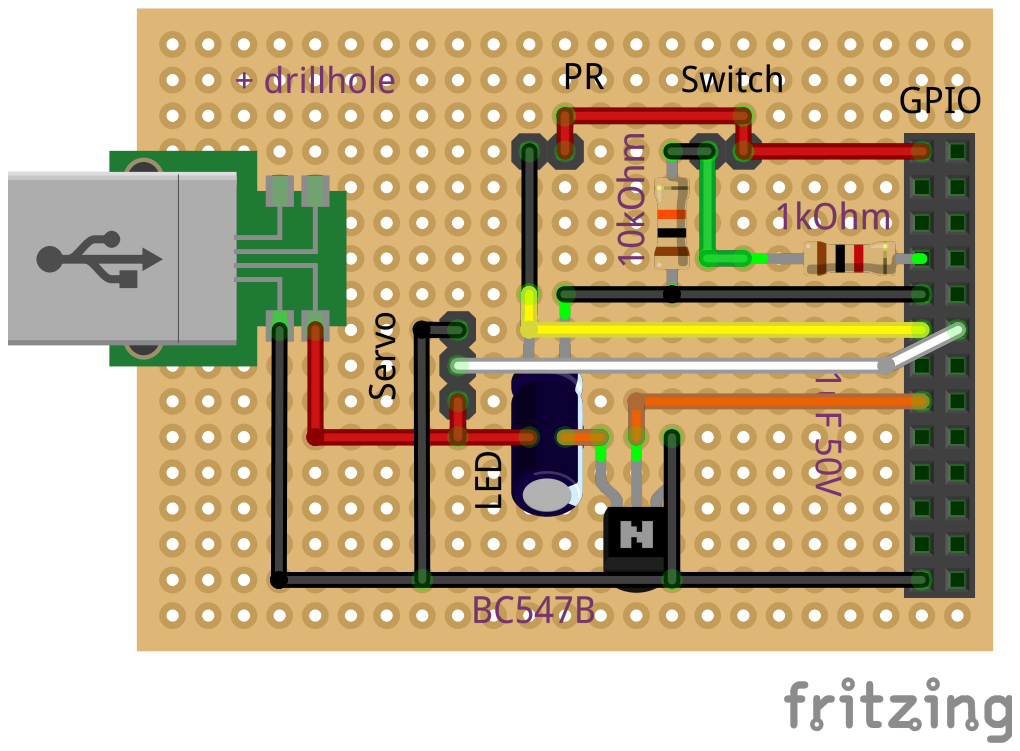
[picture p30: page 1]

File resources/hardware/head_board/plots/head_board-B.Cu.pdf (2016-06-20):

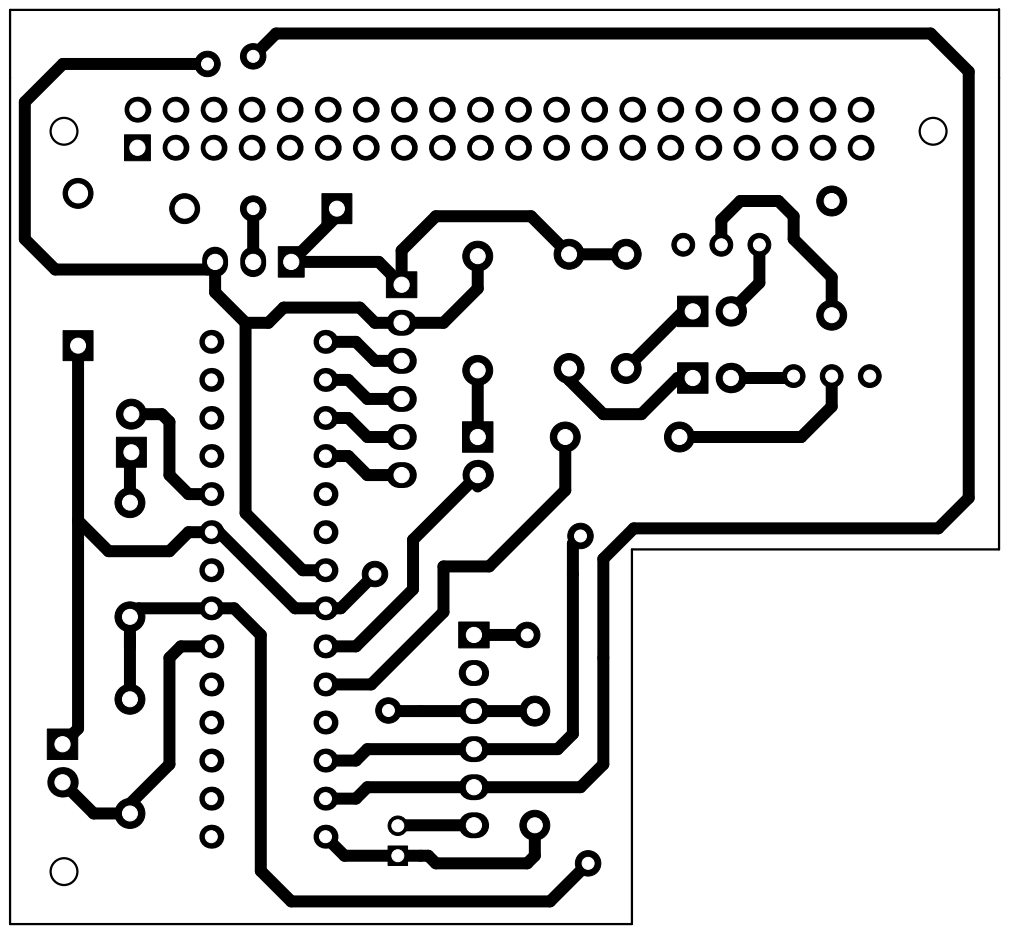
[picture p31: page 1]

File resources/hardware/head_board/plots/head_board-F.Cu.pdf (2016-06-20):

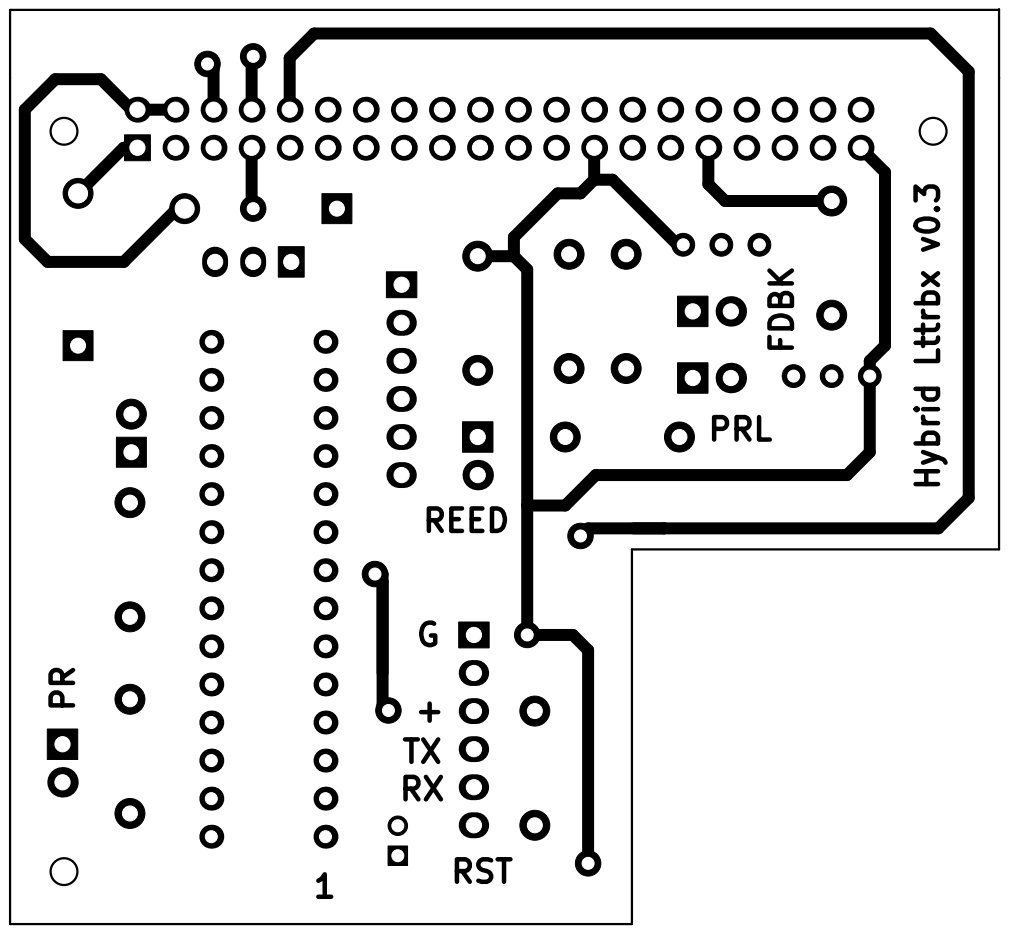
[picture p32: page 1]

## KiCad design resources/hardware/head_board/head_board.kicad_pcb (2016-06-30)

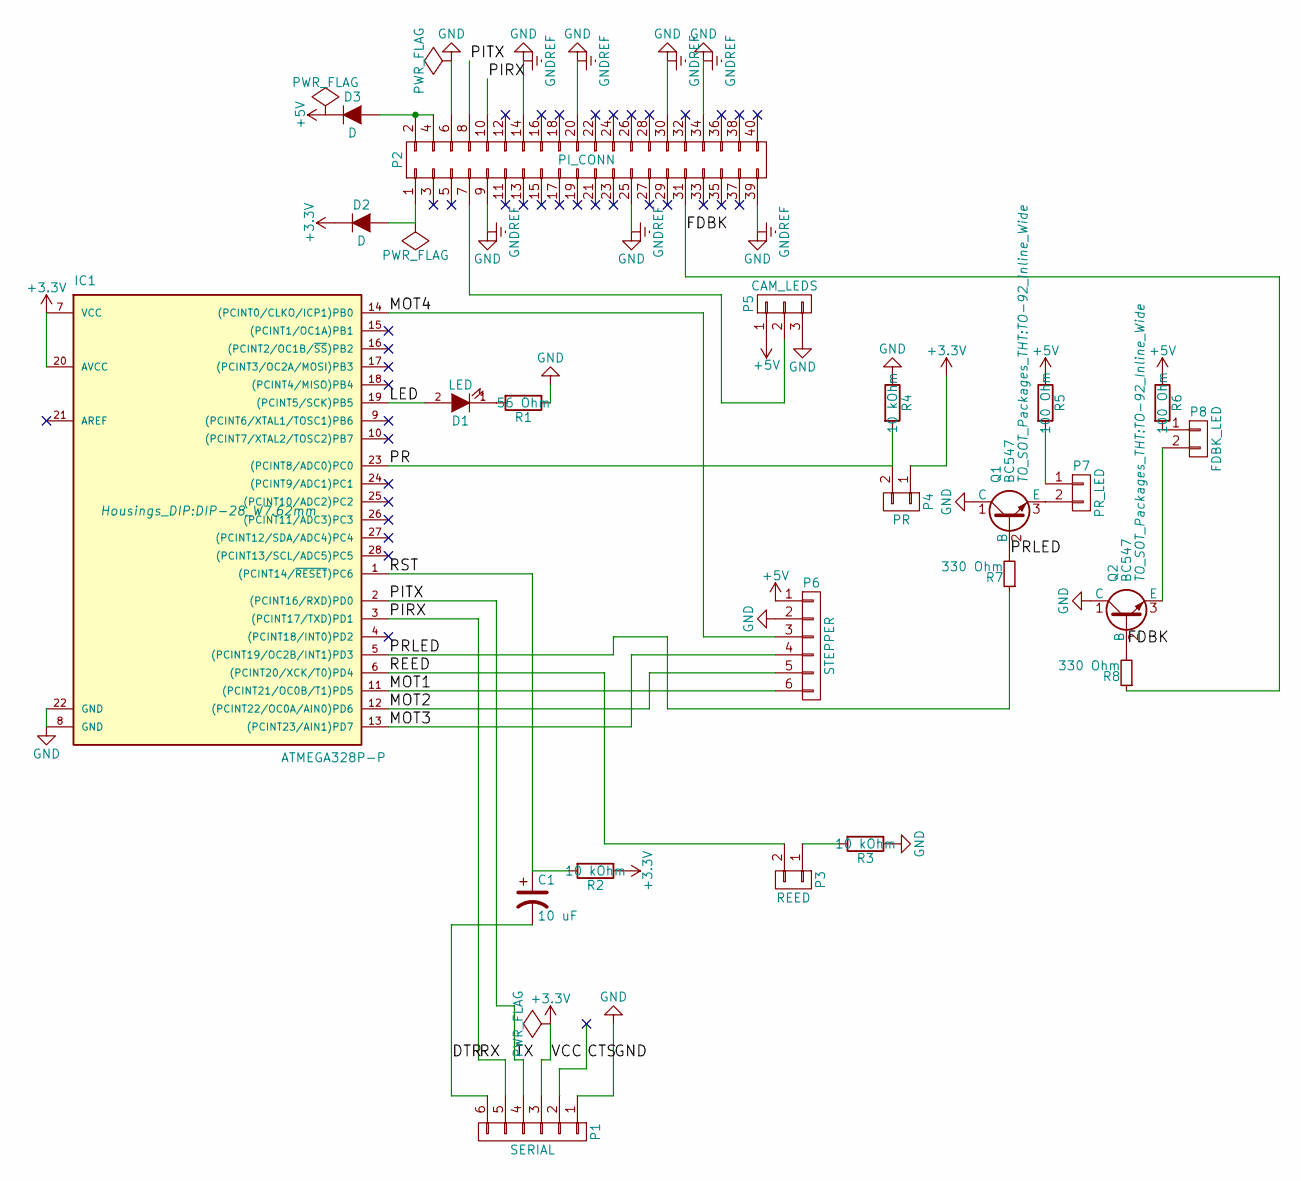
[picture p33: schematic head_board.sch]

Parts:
C1: 10 uF; C_Radial_D5_L11_P2
D1: LED; LED-3MM
D2, D3: D; Diode_DO-41_SOD81_Horizontal_RM10
IC1: ATMEGA328P-P; DIP-28_W7.62mm
P1: SERIAL; Pin_Header_Straight_1x06
P2: PI_CONN; Pin_Header_Straight_2x20
P3: REED; Pin_Header_Straight_1x02
P4: PR; Pin_Header_Straight_1x02
P5: CAM_LEDS; Pin_Header_Straight_1x03
P6: STEPPER; Pin_Header_Straight_1x06
P7: PR_LED; Pin_Header_Straight_1x02
P8: FDBK_LED; Pin_Header_Straight_1x02
Q1, Q2: BC547; TO-92_Inline_Wide
R1: 56 Ohm; Resistor_Horizontal_RM7mm
R2, R3, R4: 10 kOhm; Resistor_Horizontal_RM7mm
R5, R6: 100 Ohm; Resistor_Horizontal_RM7mm
R7, R8: 330 Ohm; Resistor_Horizontal_RM7mm

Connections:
+3V3: D2.1 (K), IC1.7 (VCC), IC1.20 (AVCC), P1.3, P4.1, R2.1
+5V: D3.1 (K), P5.1, P6.1, R5.1, R6.1
/DTR: C1.2, P1.6
/FDBK: P2.31, R8.1
/LED: D1.2 (A), IC1.19 ((PCINT5/SCK)PB5)
/MOT1: IC1.11 ((PCINT21/OC0B/T1)PD5), P6.6
/MOT2: IC1.12 ((PCINT22/OC0A/AIN0)PD6), P6.5
/MOT3: IC1.13 ((PCINT23/AIN1)PD7), P6.4
/MOT4: IC1.14 ((PCINT0/CLKO/ICP1)PB0), P6.3
/PIRX: IC1.3 ((PCINT17/TXD)PD1), P1.5, P2.10
/PITX: IC1.2 ((PCINT16/RXD)PD0), P1.4, P2.8
/PR: IC1.23 ((PCINT8/ADC0)PC0), P4.2, R4.2
/PRLED: IC1.5 ((PCINT19/OC2B/INT1)PD3), Q1.2 (B), R7.1, R7.2
/REED: IC1.6 ((PCINT20/XCK/T0)PD4), P3.2
/RST: C1.1, IC1.1 ((PCINT14/~RESET~)PC6), R2.2
GND: IC1.8 (GND), IC1.22 (GND), P1.1, P2.6, P2.9, P2.14, P2.20, P2.25, P2.30, P2.34, P2.39, P5.3, P6.2, Q1.1 (C), Q2.1 (C), R1.1, R3.1, R4.1
unnamed: D1.1 (K), R1.2
unnamed: D2.2 (A), P2.1
unnamed: D3.2 (A), P2.2, P2.4
unnamed: P2.7, P5.2
unnamed: P3.1, R3.2
unnamed: P7.1, R5.2
unnamed: P7.2, Q1.3 (E)
unnamed: P8.1, R6.2
unnamed: P8.2, Q2.3 (E)
unnamed: Q2.2 (B), R8.2

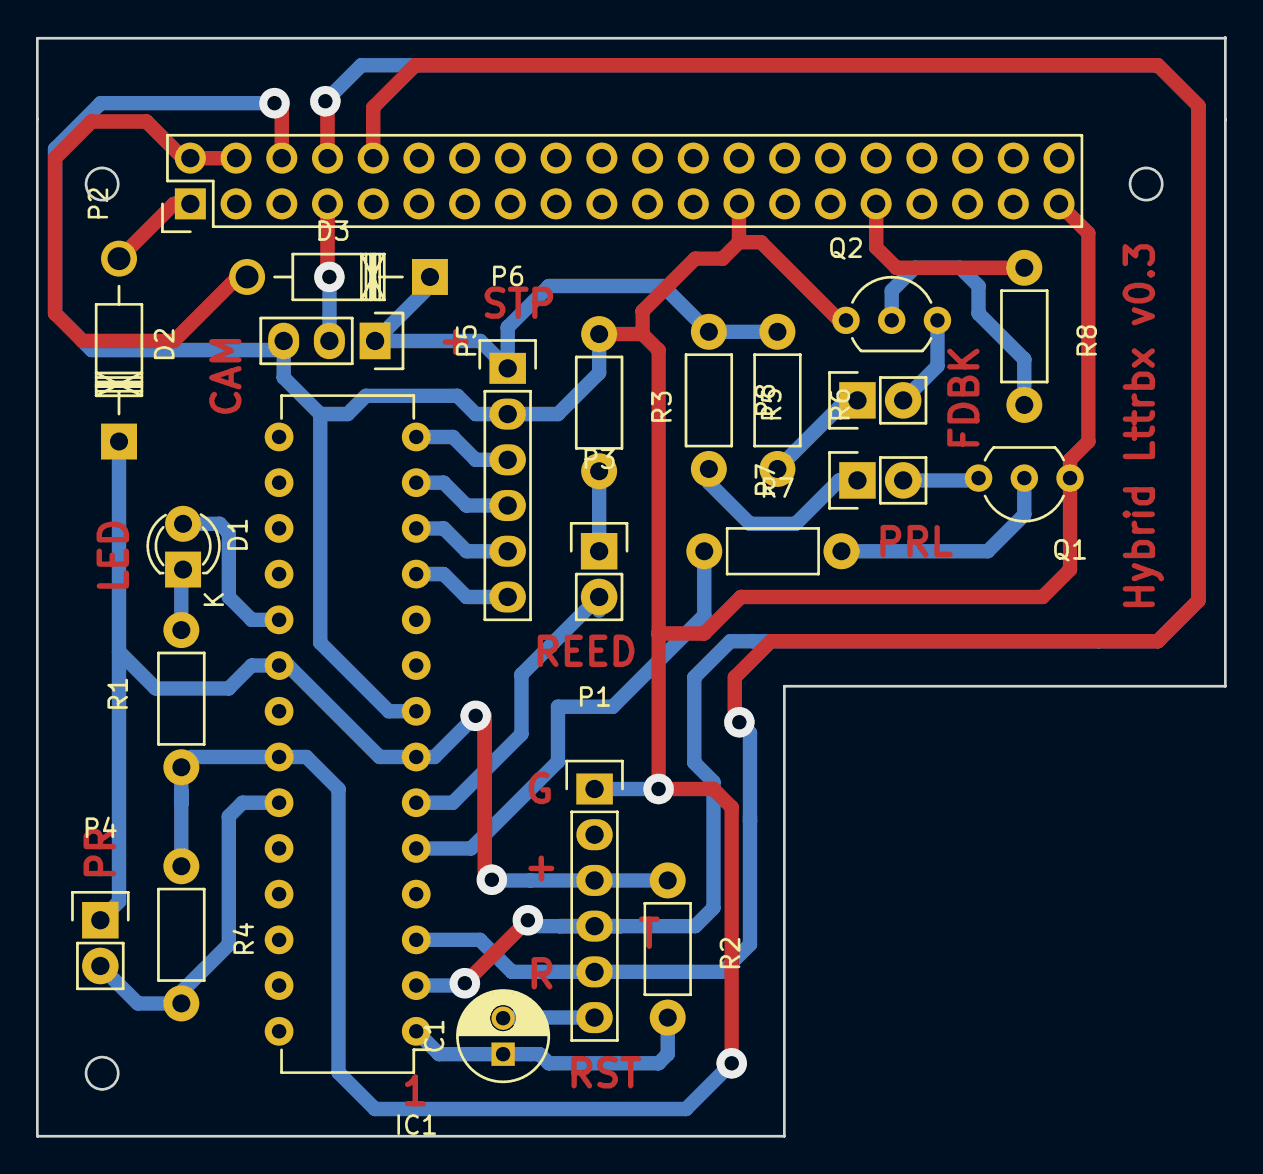
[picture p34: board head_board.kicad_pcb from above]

Board: 2 copper layers, 66.0 x 61.0 mm, 23 parts (0 on the bottom side), 26 nets.

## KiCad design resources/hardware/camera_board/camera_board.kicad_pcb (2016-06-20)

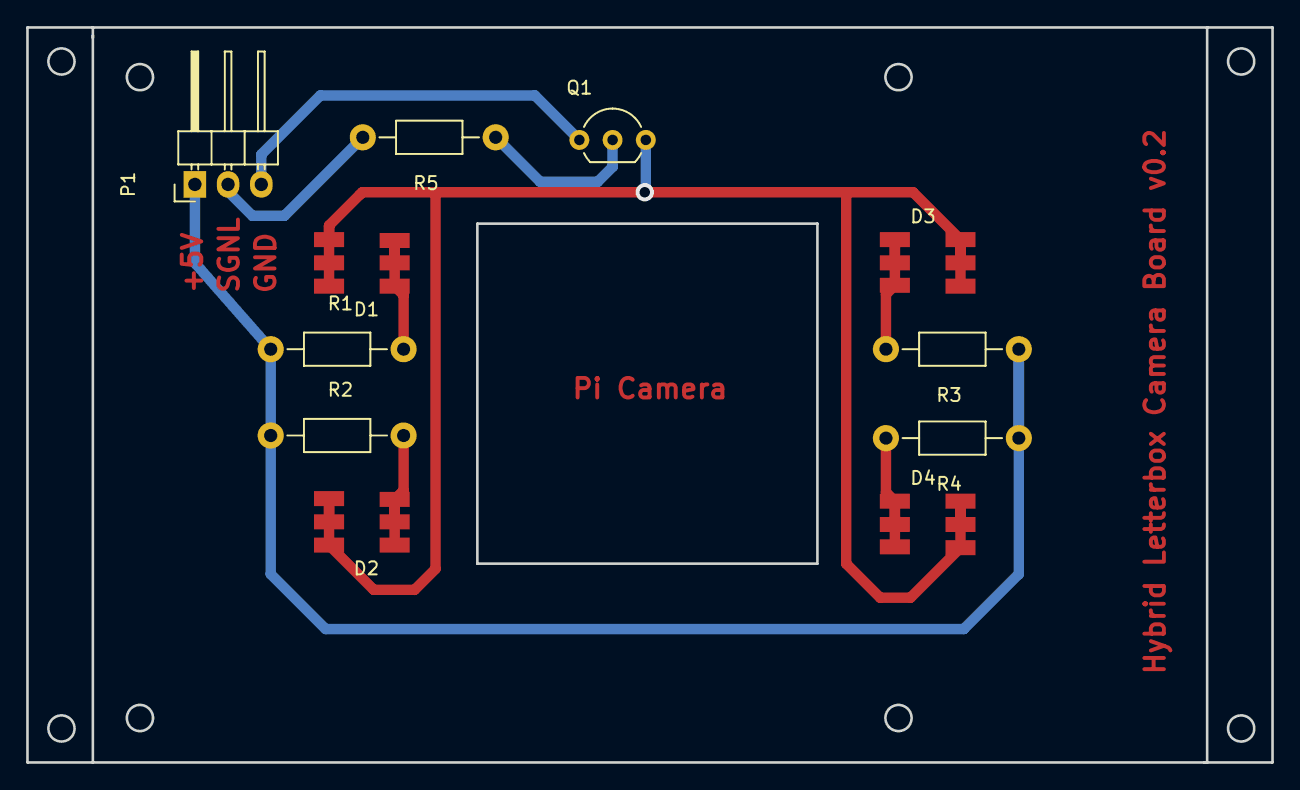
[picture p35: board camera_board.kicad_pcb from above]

Board: 2 copper layers, 95.2 x 56.2 mm, 11 parts (0 on the bottom side), 9 nets.

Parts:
D1, D2, D3, D4: LED_RGB; SMD-LED_5250
P1: CONN_01X03; Pin_Header_Angled_1x03
Q1: Q_NPN_EBC; TO-92_Inline_Wide
R1, R2, R3, R4, R5: R_Small; Resistor_Horizontal_RM10mm

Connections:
+5V: P1.1, R1.1, R2.1, R3.1, R4.1
/SGNL: P1.2, R5.2
GND: P1.3, Q1.1
unnamed: D1.1, D1.2, D1.3, D2.1, D2.2, D2.3, D3.1, D3.2, D3.3, D4.1, D4.2, D4.3, Q1.3
unnamed: D1.4, D1.5, D1.6, R1.2
unnamed: D2.4, D2.5, D2.6, R2.2
unnamed: D3.4, D3.5, D3.6, R3.2
unnamed: D4.4, D4.5, D4.6, R4.2
unnamed: Q1.2, R5.1

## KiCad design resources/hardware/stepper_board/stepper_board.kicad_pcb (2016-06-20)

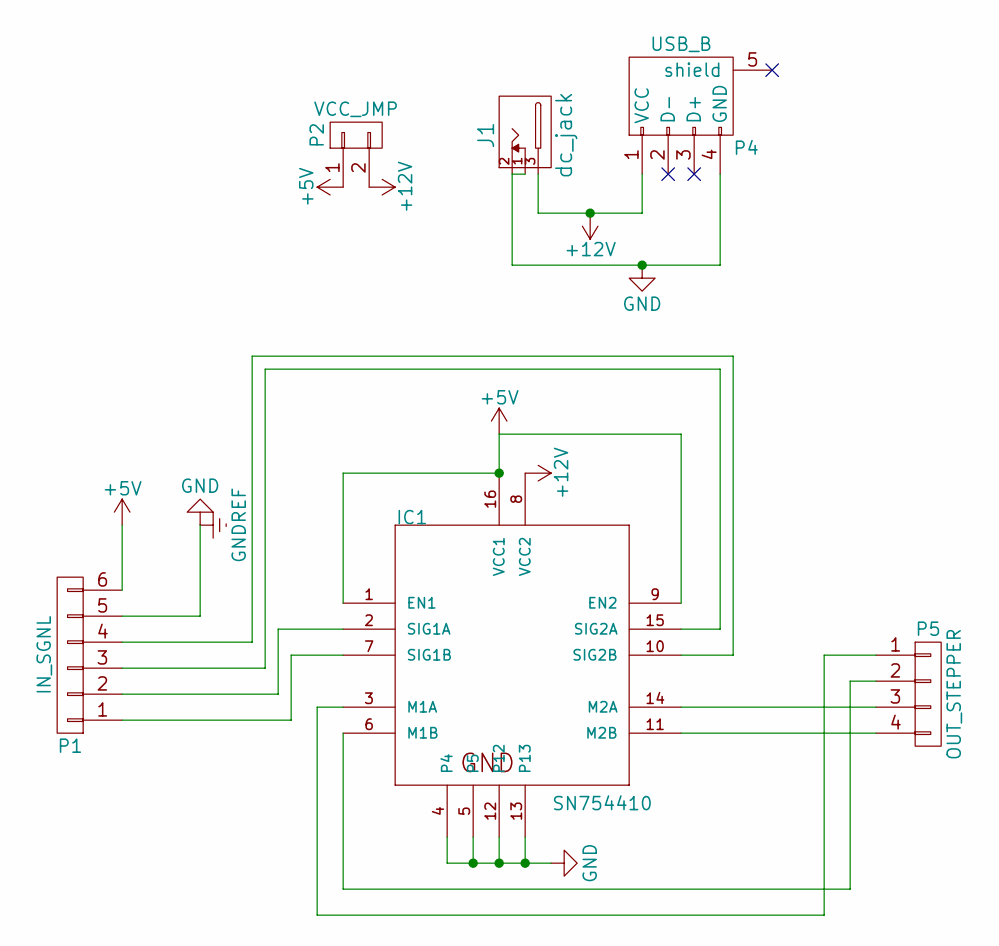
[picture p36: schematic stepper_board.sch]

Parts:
IC1: SN754410; DIP-16_W7.62mm
J1: dc_jack; dc_socket
P1: IN_SGNL; Pin_Header_Straight_1x06
P2: VCC_JMP; Pin_Header_Straight_1x02
P4: USB_B
P5: OUT_STEPPER; Pin_Header_Straight_1x04

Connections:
+5V: IC1.1 (EN1), IC1.9 (EN2), IC1.16 (VCC1), P1.6, P2.1
+12V: IC1.8 (VCC2), J1.3, P2.2, P4.1 (VCC)
GND: IC1.4, IC1.5, IC1.12, IC1.13, J1.1, J1.2, P1.5, P4.4 (GND)
unnamed: IC1.2 (SIG1A), P1.2
unnamed: IC1.3 (M1A), P5.1
unnamed: IC1.6 (M1B), P5.2
unnamed: IC1.7 (SIG1B), P1.1
unnamed: IC1.10 (SIG2B), P1.4
unnamed: IC1.11 (M2B), P5.4
unnamed: IC1.14 (M2A), P5.3
unnamed: IC1.15 (SIG2A), P1.3

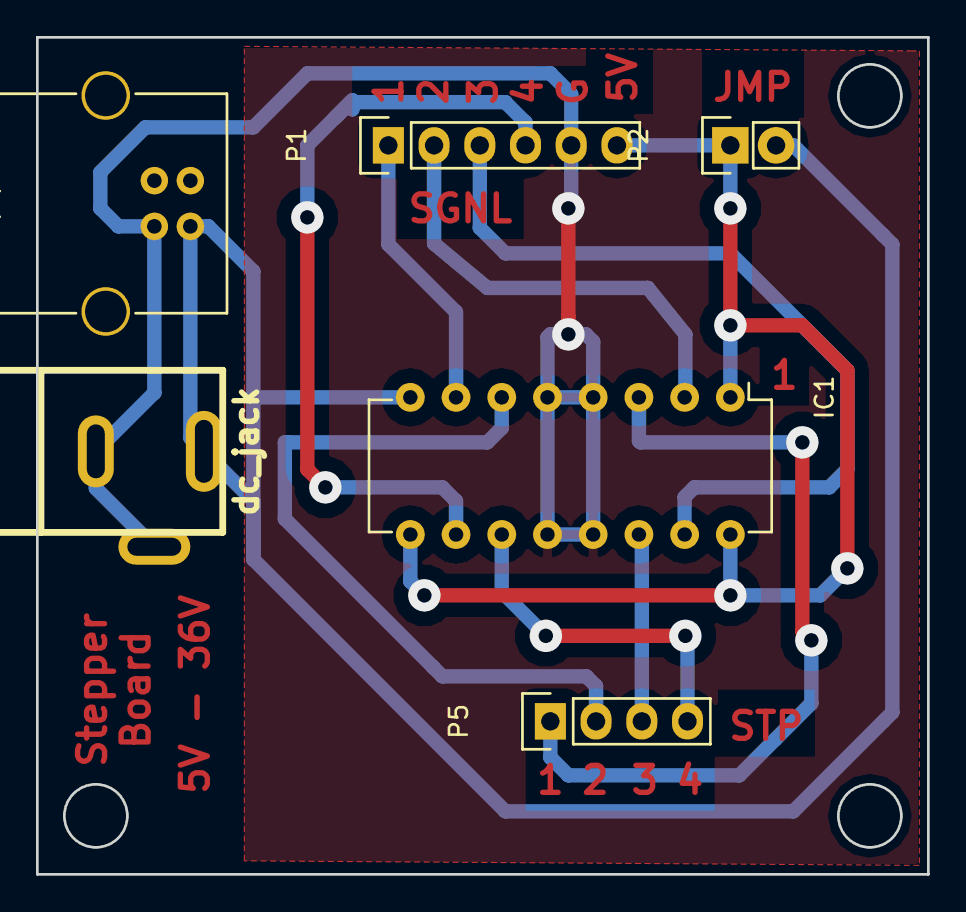
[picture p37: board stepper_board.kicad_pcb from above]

Board: 2 copper layers, 49.5 x 46.5 mm, 6 parts (0 on the bottom side), 11 nets.

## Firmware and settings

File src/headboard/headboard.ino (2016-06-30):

/*
* @Author: Lutz Reiter, Design Research Lab, Universität der Künste Berlin
* @Date:   2016-03-01 11:53:42
* @Last Modified by:   lutz
* @Last Modified time: 2016-03-03 11:46:09
*/

/* 
* Sketch for the atmega328, placed on the Hybrid Letterboxes Pi Headboard,
* Manages Stepper motor, reed switch for positioning, and photoresistor for
* detecting Postcards
* 
* Upload as "Lilypad Arduino" with atmega328.
*/

#include <string.h>
#include "StepperMotorControl.h"
#include "Photocell.h"

// PIN LAYOUTS
#define LED_STATUS_PIN 13 //IN5 on ULN2003 CONNECTED TO LED
#define PHOTORESISTOR_PIN A0 //ANALOG PIN FOR PHOTORESISTOR
#define PHOTORESISTOR_LED_PIN 3 //CONNECT PHOTORESISTOR LED TO THIS
#define MOTOR_PIN1  5 // IN1 on the ULN2003 driver 1
#define MOTOR_PIN2  6 // IN2 on the ULN2003 driver 1
#define MOTOR_PIN3  7 // IN3 on the ULN2003 driver 1
#define MOTOR_PIN4  8 // IN4 on the ULN2003 driver 1
#define REED_PIN 4 // CONNECT TO REED SWITCH

// SERIAL PARAMETERS
#define SOFTWARE_SERIAL 1 // uncomment this line for using normal serial
#define SERIAL softwareSerial // change to Serial for using normal Serial
#define RX_PIN 0 //only used  for software serial, rx = 0
#define TX_PIN 1 //only used for software serial, tx = 1
#define SERIAL_BUFFER_SIZE 16
#define SERIAL_END_CHARACTER '\n'
#define BAUD_RATE 9600

// OTHER PARAMETERS
#define CALIBRATION_TRIES 10

// SERIAL VARS
#ifdef SOFTWARE_SERIAL
#include <SoftwareSerial.h>
SoftwareSerial SERIAL(RX_PIN, TX_PIN);
#endif
char serialBuffer[SERIAL_BUFFER_SIZE]; //allow only messages of the size of eight bytes
byte serialBufferPosition = 0;

// MOTOR VARS
StepperMotorControl stepperMotor(MOTOR_PIN1, MOTOR_PIN2, MOTOR_PIN3, MOTOR_PIN4, REED_PIN);
Photocell photocell(PHOTORESISTOR_PIN,PHOTORESISTOR_LED_PIN);

// function makes the arduino reset
void (* resetArduino) (void) = 0;

void setup() {

  // setup led pin
  pinMode(LED_STATUS_PIN, OUTPUT);
  
  // start serial port
  #ifdef SOFTWARE_SERIAL
  pinMode(RX_PIN, INPUT);
  pinMode(TX_PIN, OUTPUT);
  #endif
  SERIAL.begin(BAUD_RATE);
  SERIAL.write("waiting\n");

  // send a byte to establish contact until receiver responds
  while (true) {
    if (readSerialMessages()) {
      if (compareSubString(serialBuffer,"start"))
         break;
      clearSerialBuffer();
    }
    //SERIAL.write("waiting\n");
    blinkStatusLed(50);
  }

  
  //calibrate photocell
  SERIAL.write("calibrate photocell\n");
  /*int i = 0;
  while(!photocell.calibrate()) {
    blinkStatusLed(1000);
    if (i >= CALIBRATION_TRIES -1) {
      resetArduino();
    }
    i++;
  }*/

  SERIAL.write("calibrate motor\n");
  //calibrate stepper
  stepperMotor.calibrate();

  //enable photocell
  photocell.enable(true);

  digitalWrite(LED_STATUS_PIN,HIGH); // turn status led on to signal everything is ok
  
  clearSerialBuffer();
  SERIAL.write("started\n");
}

void loop() {
 
  // process message if there is one received
  if (readSerialMessages()) {
    
   	if (compareSubString(serialBuffer,"pr:?")) {
      char response[] = "pr:?\n";
      response[3] = photocell.wasBlocked() ? '1' : '0';
      SERIAL.write(response);
   	} else if (compareSubString(serialBuffer,"stp:0") && !stepperMotor.moving) {
      stepperMotor.setPosition(STEPPER_START);
      SERIAL.write("stp:s\n");
   	} else if (compareSubString(serialBuffer,"stp:1") && !stepperMotor.moving) {
      stepperMotor.setPosition(STEPPER_TURN);
      SERIAL.write("stp:s\n");
    } else if (compareSubString(serialBuffer,"stp:2") && !stepperMotor.moving) {
      stepperMotor.setPosition(STEPPER_EJECT);
      SERIAL.write("stp:s\n");
    } else if (compareSubString(serialBuffer,"stp:c") && !stepperMotor.moving) {
      SERIAL.write("stp:c\n");
      stepperMotor.calibrate();
      SERIAL.write("stp:e\n");
    }
    else if (compareSubString(serialBuffer,"start"))
      SERIAL.write("started\n");
    else if (compareSubString(serialBuffer,"reset"))
      resetArduino();
    else
      SERIAL.write("?\n");

    clearSerialBuffer();
  }

  // update the stepper motors position
  if (stepperMotor.update())
    SERIAL.write("stp:e\n");

  // update photocell
  photocell.update();
}

boolean readSerialMessages() {
  while (SERIAL.available() > 0) {
    // get incoming byte:
    char inByte = SERIAL.read();
    
    if (inByte == SERIAL_END_CHARACTER) {
      //received end byte
      return true;
    } else if (serialBufferPosition < SERIAL_BUFFER_SIZE) {
      //add one byte
      serialBuffer[serialBufferPosition] = inByte;
      serialBufferPosition++;
    } else {
      //overflow
      clearSerialBuffer();
    }
    
    return false; // no end byte received
  }
}

void clearSerialBuffer() {
  for (int i=0;i<SERIAL_BUFFER_SIZE;i++)
    serialBuffer[i] = (char)0;
  serialBufferPosition = 0;
}

bool compareSubString(char* string, String compareString) {
  for (int i=0;i<compareString.length();i++) {
    if (string[i] != compareString[i])
      return false;
  }
  return true;
}

void blinkStatusLed(int delaytime) {
  digitalWrite(LED_STATUS_PIN,HIGH);
  delay(delaytime);
  digitalWrite(LED_STATUS_PIN,LOW);
  delay(delaytime);
}

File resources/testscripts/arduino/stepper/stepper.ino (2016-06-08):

#include <Bounce2.h>
#include <AccelStepper.h>
#include "stepper.h"

// Stepper Motor definitions
#define HALFSTEP 8
#define MOTOR_MAX_SPEED 1000.0
#define MOTOR_ACCELLERATION 250.0
#define MOTOR_FULL_TURN 64*64

#define MOTOR_PIN1  0     // IN1 on the ULN2003 driver 1
#define MOTOR_PIN2  1     // IN2 on the ULN2003 driver 1
#define MOTOR_PIN3  2     // IN3 on the ULN2003 driver 1
#define MOTOR_PIN4  3     // IN4 on the ULN2003 driver 1

//Reed switch definitions
#define REED_SWITCH_PIN 10
#define DEBOUNCE_INTERVAL 10 //in miliseconds

// Initialize with pin sequence IN1-IN3-IN2-IN4 for using the AccelStepper with 28BYJ-48
AccelStepper stepper(HALFSTEP, MOTOR_PIN1, MOTOR_PIN3, MOTOR_PIN2, MOTOR_PIN4);
int stepperStartPos = 0;

//init reed switch bouncer
Bounce reedSwitch = Bounce(); 

void setup() {

	// setup stepper motor
	stepper.setMaxSpeed(MOTOR_MAX_SPEED);
	stepper.setAcceleration(MOTOR_ACCELLERATION);
	stepper.setSpeed(0);

	// setup reed sensor
	pinMode(REED_SWITCH_PIN, INPUT_PULLUP);
	reedSwitch.attach(REED_SWITCH_PIN);
	reedSwitch.interval(DEBOUNCE_INTERVAL);

	//stepper.moveTo(513*4); // full rotation: 513*4
	
	// start calibration of the stepper motor
	stepperStartPos = calibrateStepper();

	// move to start position
	//setStepperPosition(STEPPER_START);
	stepper.moveTo(stepperStartPos);
	
}

void loop() {

  	//Change direction when the stepper reaches the target position
	if (stepper.distanceToGo() != 0) {
		stepper.run();
	}
	
}

int calibrateStepper() {

	int start1 = 0;
	int start2 = 0;

	stepper.setSpeed(MOTOR_ACCELLERATION); //move slowly to begin of reed switch
	while (readReedSwitch() == HIGH) {
		stepper.runSpeed();
	}
	start1 = stepper.currentPosition(); //move slowly to end of reed switch
	while (readReedSwitch() == LOW) {
		stepper.runSpeed();
	}
	start2 = stepper.currentPosition();

	// calculate middle position
	return (start2 - start1)/2 + start1;
}

void setStepperPosition(StepperPosition position) {
	if (position == STEPPER_EJECT)
		stepper.moveTo(stepperStartPos + MOTOR_FULL_TURN*0.75);
	else if (position == STEPPER_TURN)
		stepper.moveTo(stepperStartPos + MOTOR_FULL_TURN/2);
	else 
		stepper.moveTo(stepperStartPos);
}

int readReedSwitch() {
	reedSwitch.update();
	return reedSwitch.read();
}

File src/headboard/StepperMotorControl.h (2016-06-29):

#ifndef StepperMotorControl_h
#define StepperMotorControl_h

#include <Arduino.h>
#include <Bounce2.h>
#include "AccelStepper.h"

#define MOTOR_MAX_SPEED 500.0
#define MOTOR_ACCELLERATION 200.0
#define MOTOR_CALIBRATION_SPEED 50.0
#define MOTOR_START_POS_OFFSET 1
#define MOTOR_FULL_TURN 201
#define MOTOR_GEAR_OFFSET 0 //If the steppers gearbox axis is loose, correct calibration position by this offset
#define NUM_MOTOR_PINS 4
#define HALFSTEP 8

#define LED_STATUS_PIN 13

//reed switch debounce interval
#define DEBOUNCE_INTERVAL 10 //in miliseconds

enum StepperPosition {
  STEPPER_START, // default position
  STEPPER_TURN, // turn by 180 degrees
  STEPPER_EJECT // throw out postcard
};

class StepperMotorControl {

  public:
    bool moving = false;

  private:
    AccelStepper stepper;
    Bounce reedSwitch;

  public:
    
    StepperMotorControl() { };
    
    StepperMotorControl(byte motorPin1, byte motorPin2, byte motorPin3, byte motorPin4, byte reedPin) {
      // setup motor
      stepper = AccelStepper(AccelStepper::FULL4WIRE, motorPin1, motorPin2, motorPin3, motorPin4);
      stepper.setMaxSpeed(MOTOR_MAX_SPEED);
      stepper.setAcceleration(MOTOR_ACCELLERATION);
      stepper.setSpeed(0);

      // setup reed switch
      pinMode(reedPin, INPUT_PULLUP);
      this->reedSwitch = Bounce();
      reedSwitch.attach(reedPin);
      reedSwitch.interval(DEBOUNCE_INTERVAL);
    }

    // TODO: add calibration error function
    void calibrate() {

      moving = true;

      long start1 = 0;
      long start2 = 0;

      this->readReedSwitch();
      delay(100);

      //check if it is already close to the start position, if yes, turn backwards by 45 degrees
      while (this->readReedSwitch() == LOW) {
        stepper.move(-MOTOR_FULL_TURN/8);
        stepper.runToPosition();
        this->readReedSwitch();
      }
      

      // start forward calibration
      stepper.setSpeed(MOTOR_CALIBRATION_SPEED);
      while (this->readReedSwitch() == HIGH) {
        this->stepper.runSpeed();
      }
      
      start1 = this->stepper.currentPosition(); //move slowly to end of reed switch
      while (this->readReedSwitch() == LOW) {
        this->stepper.runSpeed();
        
      }
      start2 = this->stepper.currentPosition();
      stepper.setSpeed(0);

      // calculate middle position
      long stepperStartPos = start1 + MOTOR_START_POS_OFFSET;

      //move to start position
      stepper.moveTo(stepperStartPos);
      stepper.runToPosition();

      //reset current position to zero
      stepper.setCurrentPosition(0);

      moving = false;
    }

    void setPosition(StepperPosition position) {
      moving = true;
      if (position == STEPPER_EJECT)
        stepper.moveTo(MOTOR_FULL_TURN * 0.8);
      else if (position == STEPPER_TURN)
        stepper.moveTo(MOTOR_FULL_TURN * 0.5);
      else {
        stepper.moveTo(0);
      }
    }

    int readReedSwitch() {
      reedSwitch.update();
      return reedSwitch.read();
    }

    //returns true when reached position
    bool update() {
      if (stepper.distanceToGo() != 0) {
        stepper.run();
      } else if (moving) {
        moving = false;
        return true;
      }
      return false;
    }
};

#endif

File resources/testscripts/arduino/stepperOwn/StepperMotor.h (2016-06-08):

#ifndef StepperMotor_h
#define StepperMotor_h

#include <Arduino.h>

#define MOTOR_MAX_SPEED 1000.0
#define MOTOR_ACCELLERATION 250.0
#define MOTOR_FULL_TURN 64*64
#define NUM_MOTOR_PINS 4

class StepperMotor {

  private:
      /// The current absolution position in steps.
    uint8_t _motorPin[NUM_MOTOR_PINS];
    unsigned long _lastStepTime;
    unsigned long _stepInterval;

  public:
    long currentPosition;
    float speed;

  public:

    StepperMotor() { };

    StepperMotor(byte pin1, byte pin2, byte pin3, byte pin4) {
      _motorPin[0] = pin1;
      _motorPin[1] = pin2;
      _motorPin[2] = pin3;
      _motorPin[3] = pin4;

      for (int i=0;i<NUM_MOTOR_PINS;i++)
        pinMode(_motorPin[i], OUTPUT);

      _stepInterval = 10000;

      _lastStepTime = 0;

      speed = 50;

    };

    void runSpeed() {

      unsigned long time = micros();
      unsigned long nextStepTime = _lastStepTime + _stepInterval;

      if (time >= nextStepTime) {

        _lastStepTime = time;
        
        if (speed > 0) {
            // Clockwise
            currentPosition += 1;
        }
        else {
            // Anticlockwise  
            currentPosition -= 1;
        }

      }

      step(currentPosition);
    };

    void moveTo(long position) {

    };

    void step(long step) {
      switch (step & 0x7)
      {
        case 0:    // 1000
        setOutputPins(0b0001);
        break;

        case 1:    // 1010
        setOutputPins(0b0101);
        break;

        case 2:    // 0010
        setOutputPins(0b0100);
        break;

        case 3:    // 0110
        setOutputPins(0b0110);
        break;

        case 4:    // 0100
        setOutputPins(0b0010);
        break;

        case 5:    //0101
        setOutputPins(0b1010);
        break;

        case 6:    // 0001
        setOutputPins(0b1000);
        break;

        case 7:    //1001
        setOutputPins(0b1001);
        break;
      }
    }

  private:

    void setOutputPins(uint8_t mask)
    {

      for (uint8_t i = 0; i < NUM_MOTOR_PINS; i++)
        digitalWrite(_motorPin[i], (mask & (1 << i)) ? HIGH : LOW );
    }

};

#endif

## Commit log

2016-01-13 added hardware specs
    [letterbox_board_pcb.fzz]
2016-01-18 added kicad template
    [letterbox_pcb.kicad_pcb]
2016-02-04 added first version of came pcbs
    [camera_board.kicad_pcb, camera_board.sch]
2016-02-08 added new pcb version of camera board for wired leds
    [camera_board.kicad_pcb, camera_board.sch]
2016-02-11 changed pcb layout, changed installation instructions
    [camera_board.kicad_pcb, camera_board.sch]
2016-02-11 changed dir structure
    [camera_board.kicad_pcb, camera_board.sch]
2016-02-17 changed pcbs designs
    [camera_board.kicad_pcb, camera_board.sch, letterbox_board.fzz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]
2016-02-25 added lasercut sketches for outer frame
    [back1.dxf, back2.dxf, back3.dxf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]
2016-03-01 added first sketch for headboard, made some changes on outer frame
    [back1.dxf, back2.dxf, front1_x5.dxf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]
2016-03-09 new version of headband sketch, reworked camera board on 4 led version
    [camera_board.sch]
2016-03-16 new designs for pcbs
    [camera_board.kicad_pcb, camera_board.sch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]
2016-03-16 cleaned up hardware folder
    [camera_board.kicad_pcb, camera_board.sch, letterbox_board.fzz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]
2016-03-21 reorganised master branch, added camera calibration code
2016-03-21 added pdf templates for calibration postcards
2016-03-24 added letterbox-setup.py
    [camera_board.sch, head_board.kicad_pcb, head_board.sch]
2016-03-29 wrote serial thread python class
2016-03-30 added stepper communication
2016-03-31 created CameraCalibrator
2016-03-31 blink led
2016-04-04 added calibration setup script
2016-04-14 wrote threshold, extractRegion and findMarker for cardScanner class
    [camera_board.kicad_pcb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]
2016-04-26 added pattern scanner
    [camera_board.kicad_pcb]
2016-04-27 added node socket.io unit tests
2016-04-28 added feedback socket
2016-06-02 added stepper board
    [head_board.kicad_pcb, head_board.sch, stepper_board.kicad_pcb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]
2016-06-05 finished new headboard pcbs
    [head_board.kicad_pcb, head_board.sch]
2016-06-06 deleted old headboard, modified new
    [head_board.kicad_pcb, head_board.sch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]
2016-06-15 fixed socket url adress for www app
2016-06-16 added socket io clien package
2016-06-16 changed button shadow
2016-06-20 changed headboard sketch
    [head_board.kicad_pcb]
2016-06-20 changed headboard pcbs layout, implemented marker detection, minor bug fixed on www
    [camera_board.kicad_pcb, head_board.kicad_pcb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]
2016-06-20 added letterbox control class for old prototype
2016-06-21 created postcard templates, bugfixes
    [letterboxControlTest.py, letterboxControlV1.py]
2016-06-21 bugfixes for running on prototype2
    [letterboxControlV1.py]
2016-06-22 moved device version to ini file
2016-06-22 added async eject function vor prototype 2
2016-06-27 added schematic plots
2016-06-28 added pcbs schematics
2016-06-29 bug fixing headboard code: photocell readings
    [Photocell.h, StepperMotorControl.h, headboard.ino]
2016-06-30 fixed some pcbs issues
    [head_board.kicad_pcb, head_board.sch]
2016-07-24 changed calibration script
2016-08-18 added motor test
2016-08-18 added new calibration template card
2016-08-24 adopted to new camera
2016-08-25 changed photocell calibration function
2016-08-29 close button change
